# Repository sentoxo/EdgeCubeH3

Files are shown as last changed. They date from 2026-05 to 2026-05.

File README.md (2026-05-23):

# EdgeCubeH3
Work in proggress

Custom, cheap, simple and hand-solder single-board computer with allwinner H3 CPU. Compatibilie with Orange Pi One OS's likes Armbian.

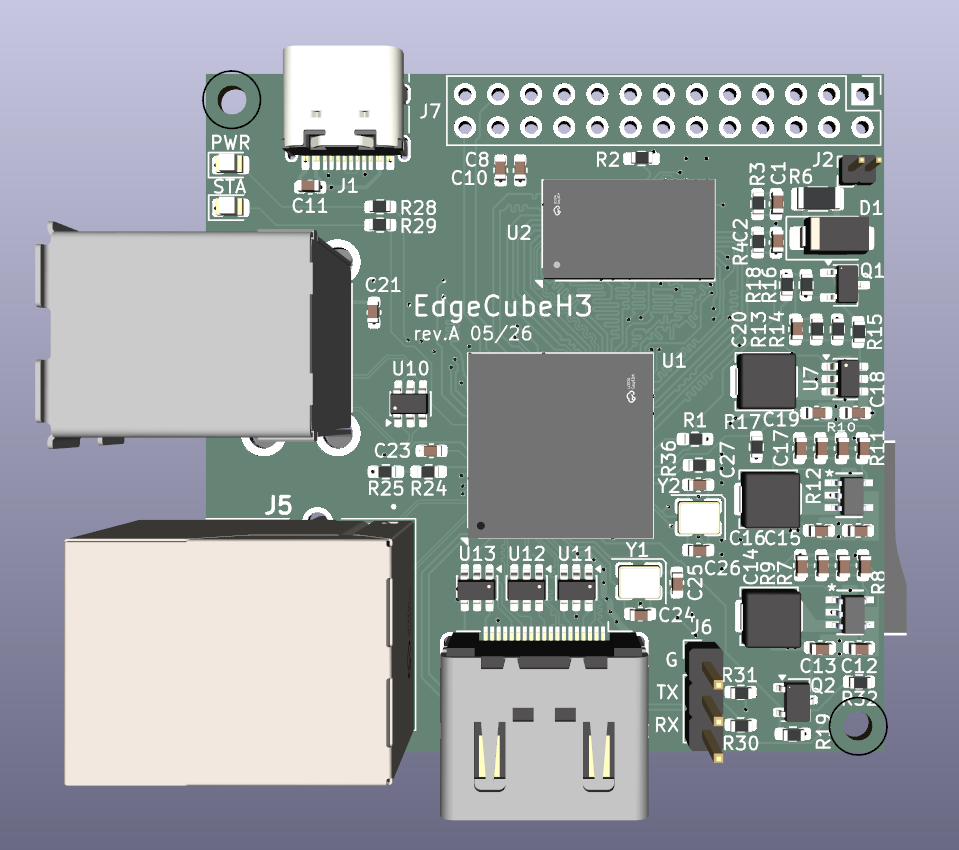
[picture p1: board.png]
board2 image


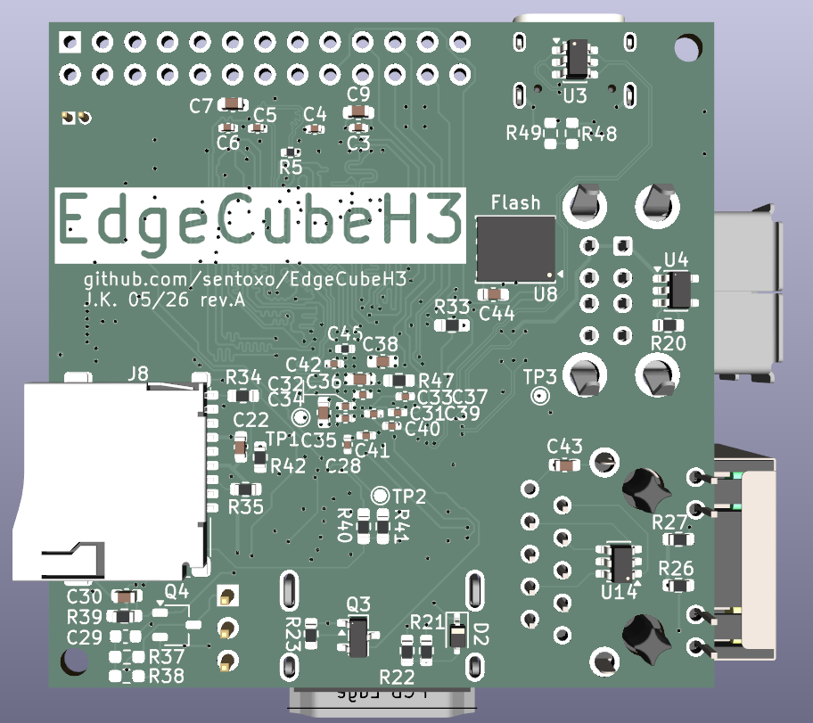
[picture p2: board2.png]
board image


## Features

- H3 Quad-Core ARM Cortex-A7 @ 1.2GHz CPU
    - Mali400 MP2 OpenGL ES 2.0 GPU
- 512MiB of DDR3L RAM, 16b
- 16MB SPI FLASH (Optional)
- Ethernet PHY, 100Mb/s
- GPDI video out
- USB connectors:
    - 2x USB-A 
    - 1x USB-C
- uSD card slot
- GPIO
- Small format 52x52mm

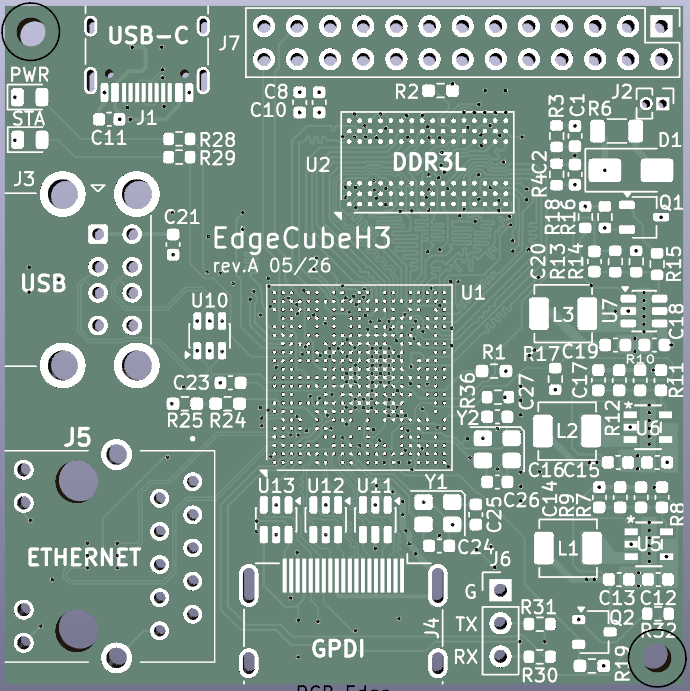
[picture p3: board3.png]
board image


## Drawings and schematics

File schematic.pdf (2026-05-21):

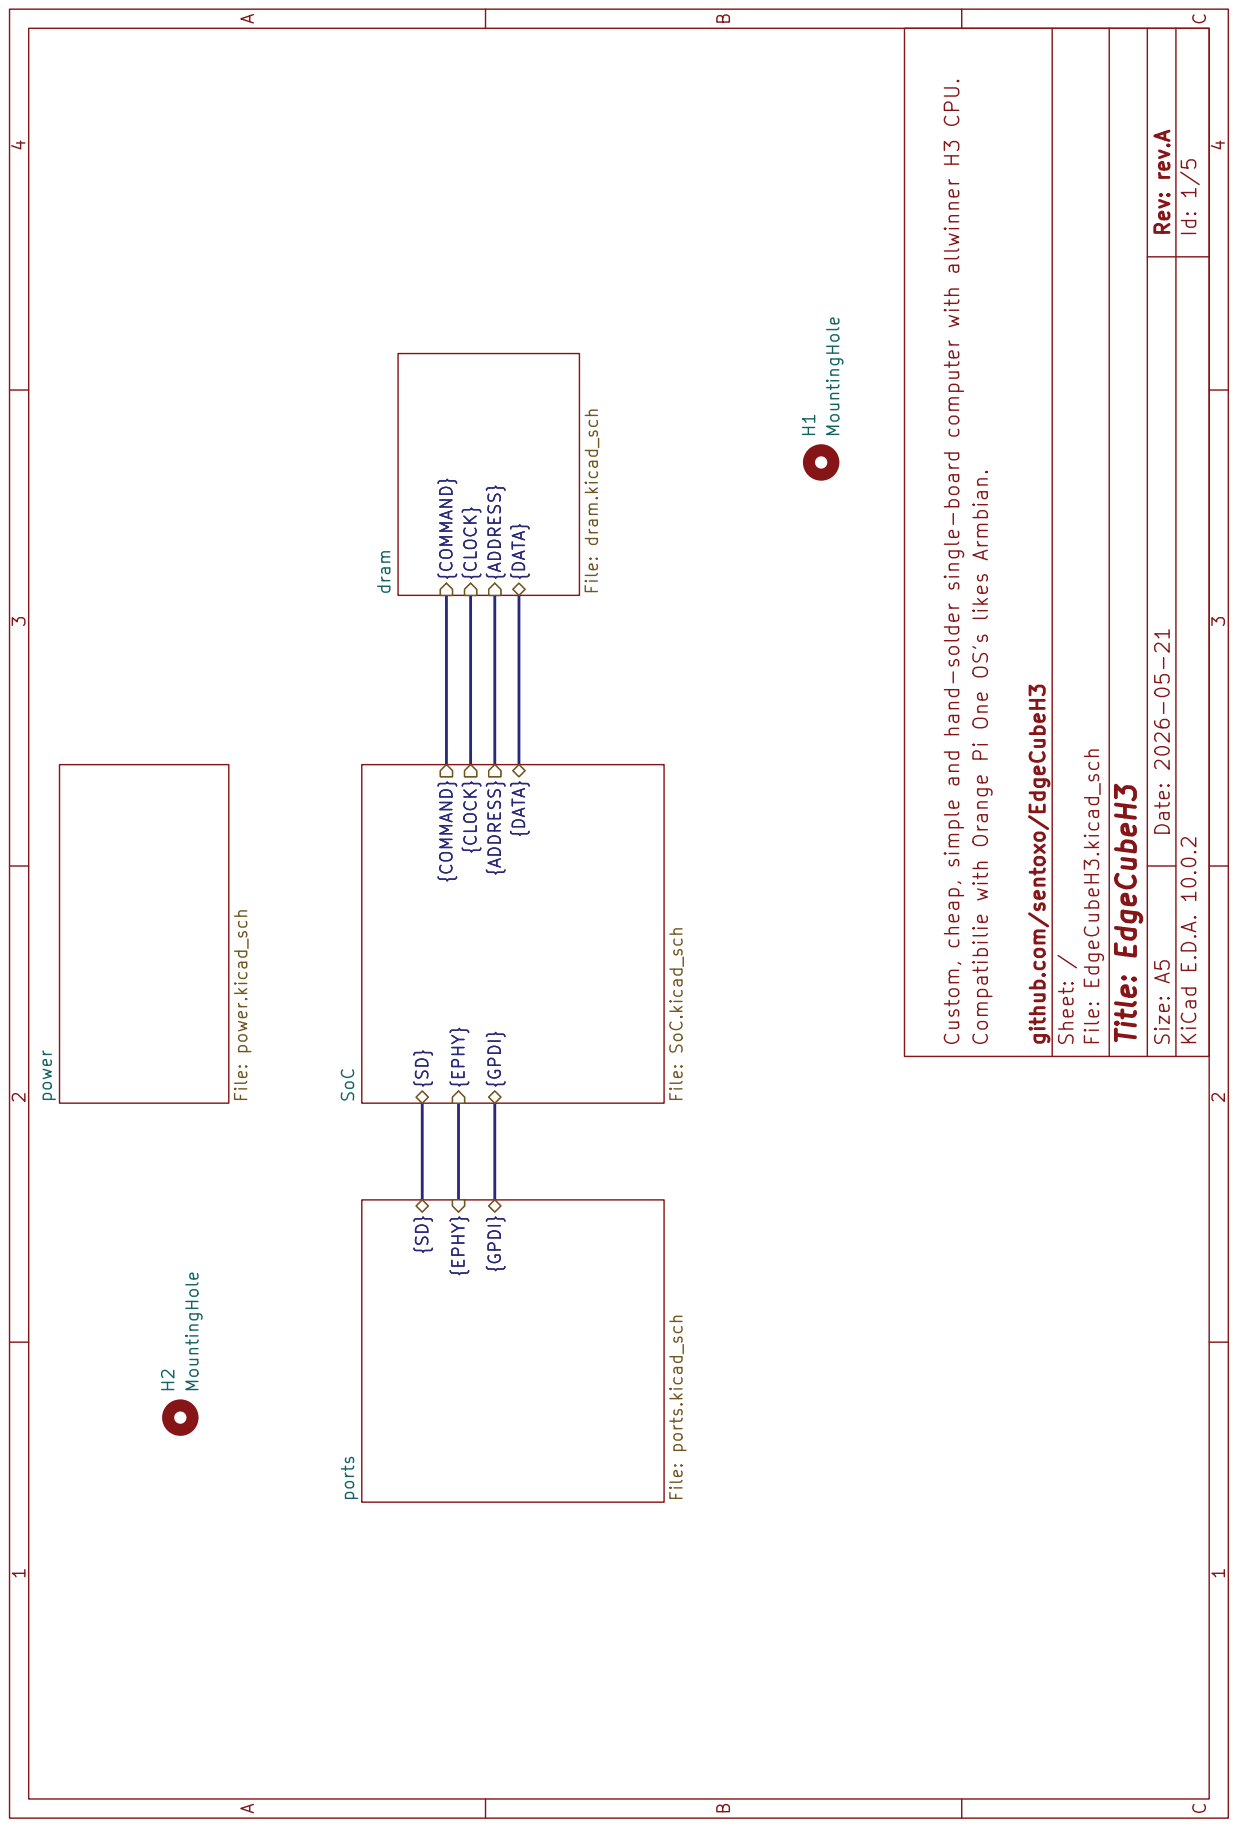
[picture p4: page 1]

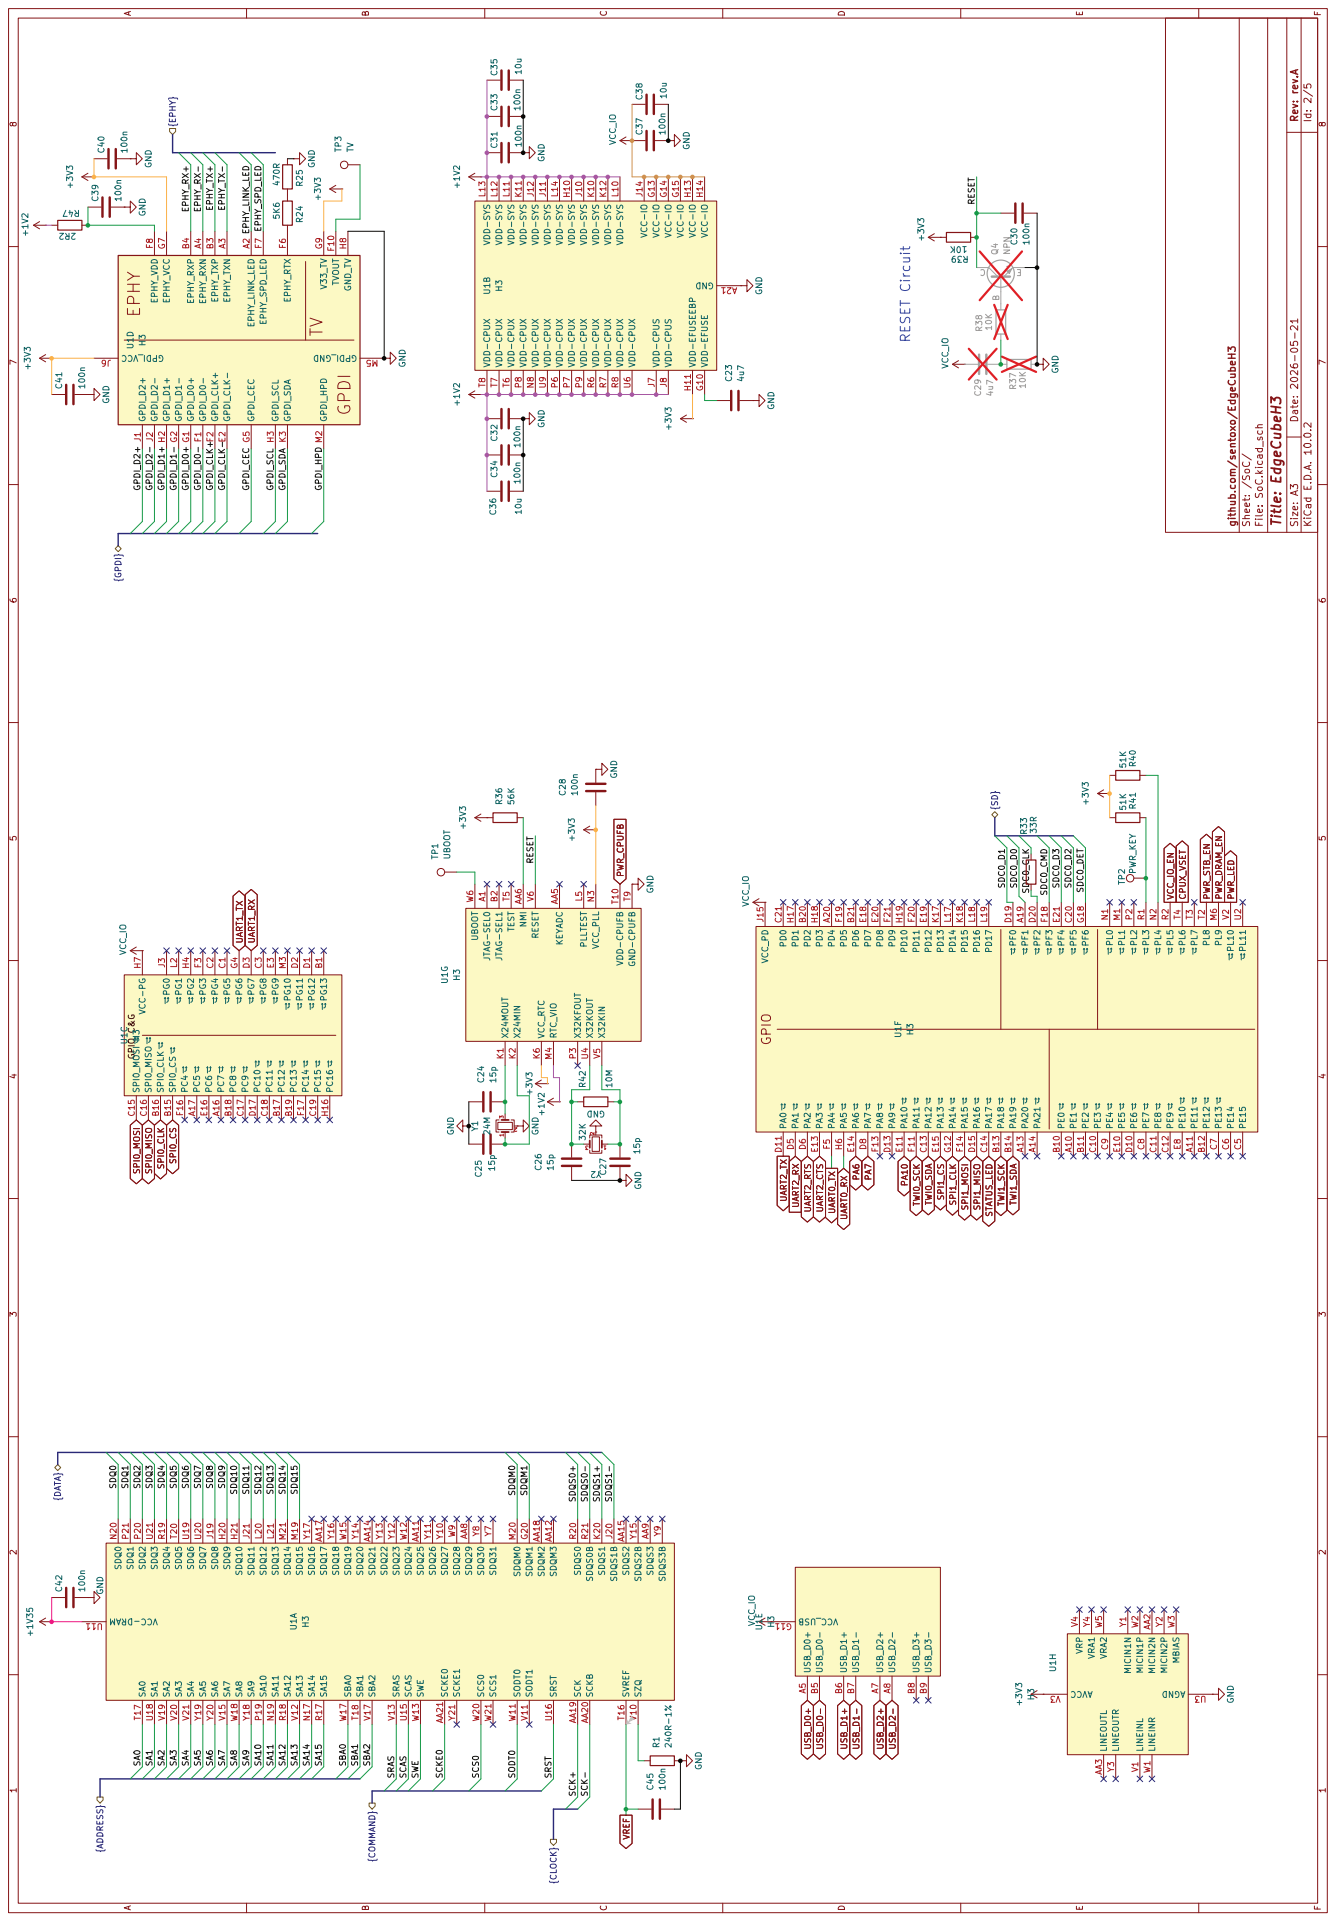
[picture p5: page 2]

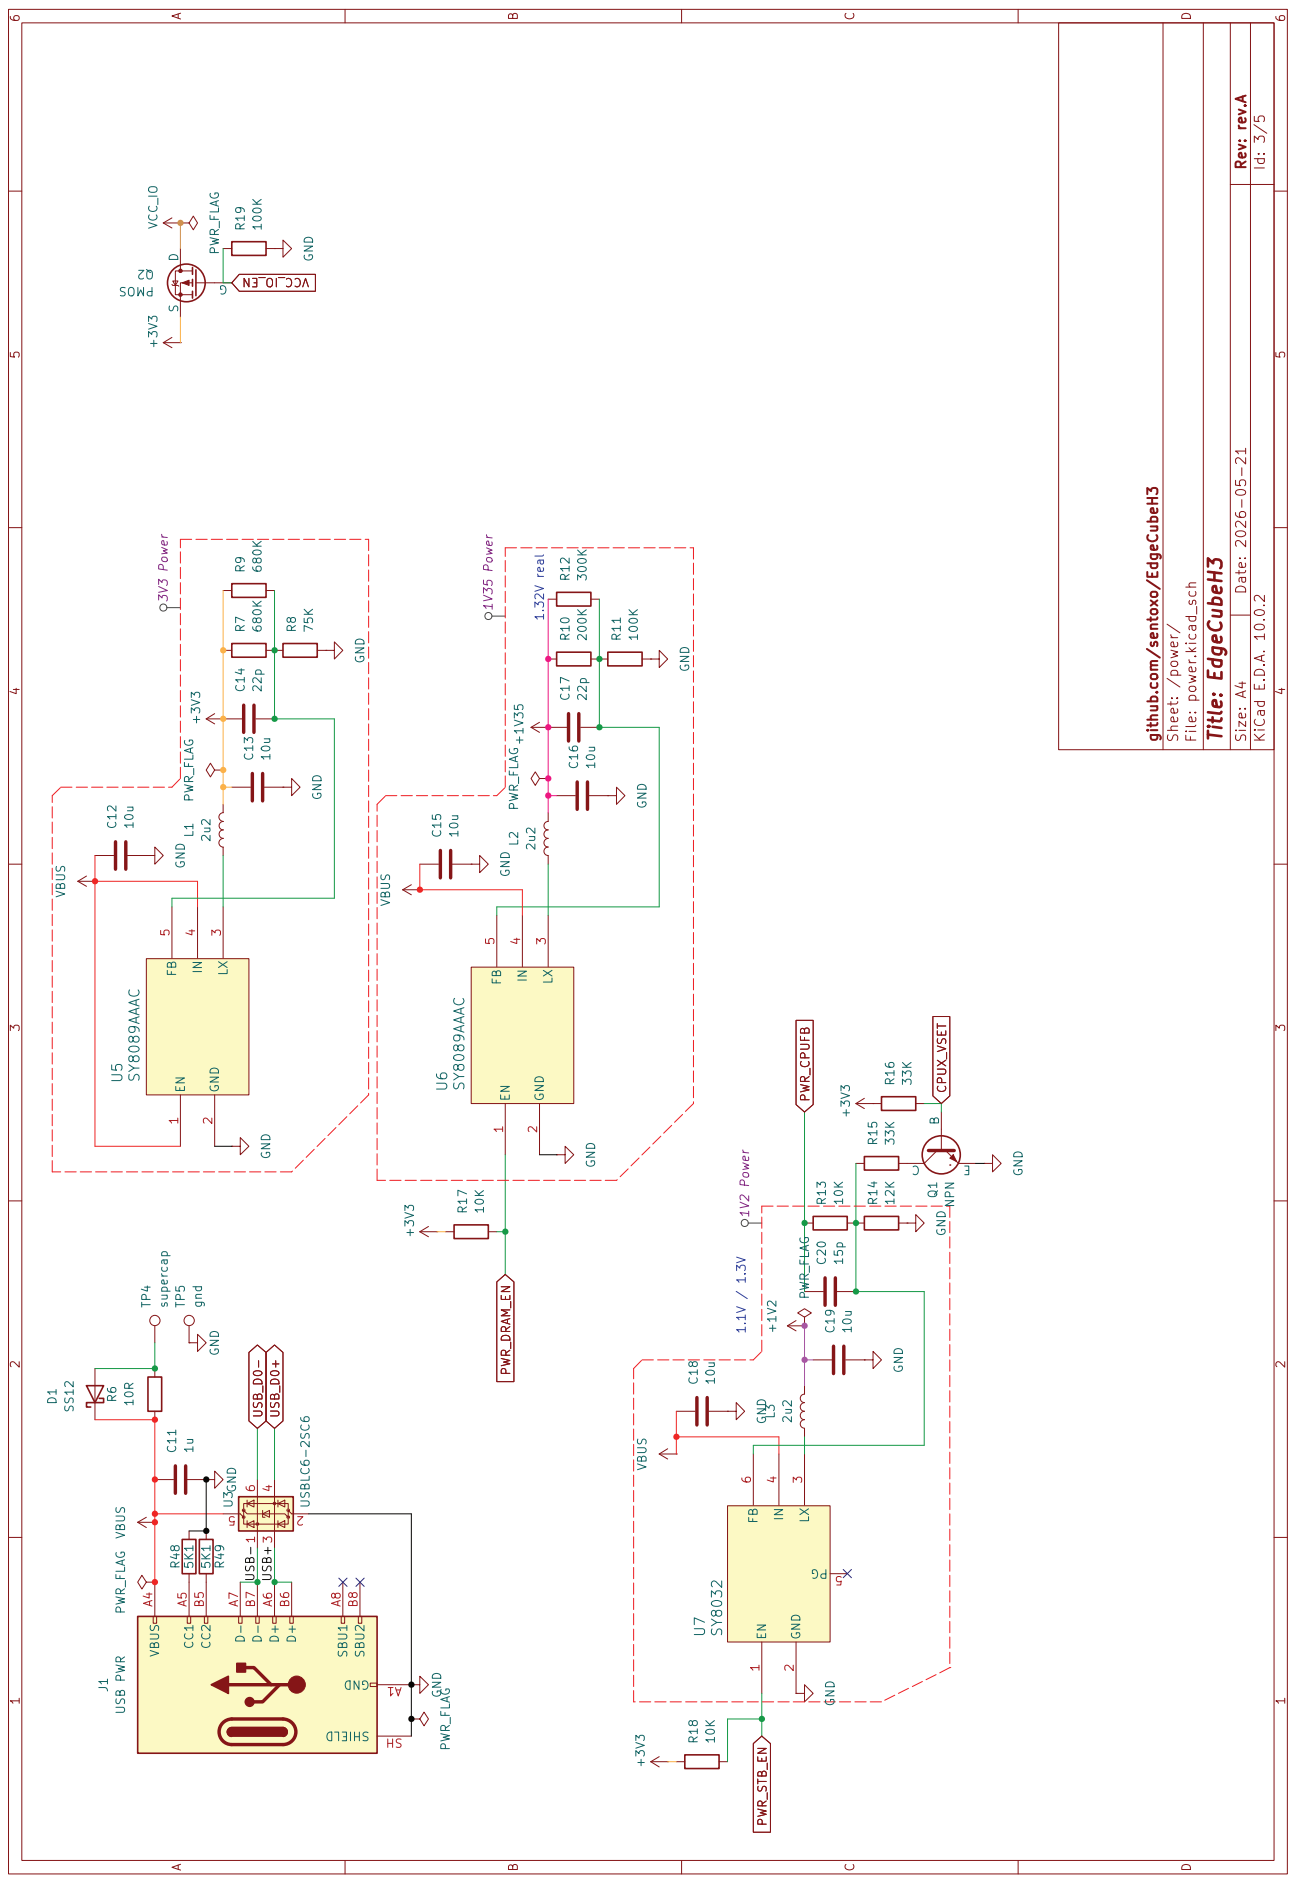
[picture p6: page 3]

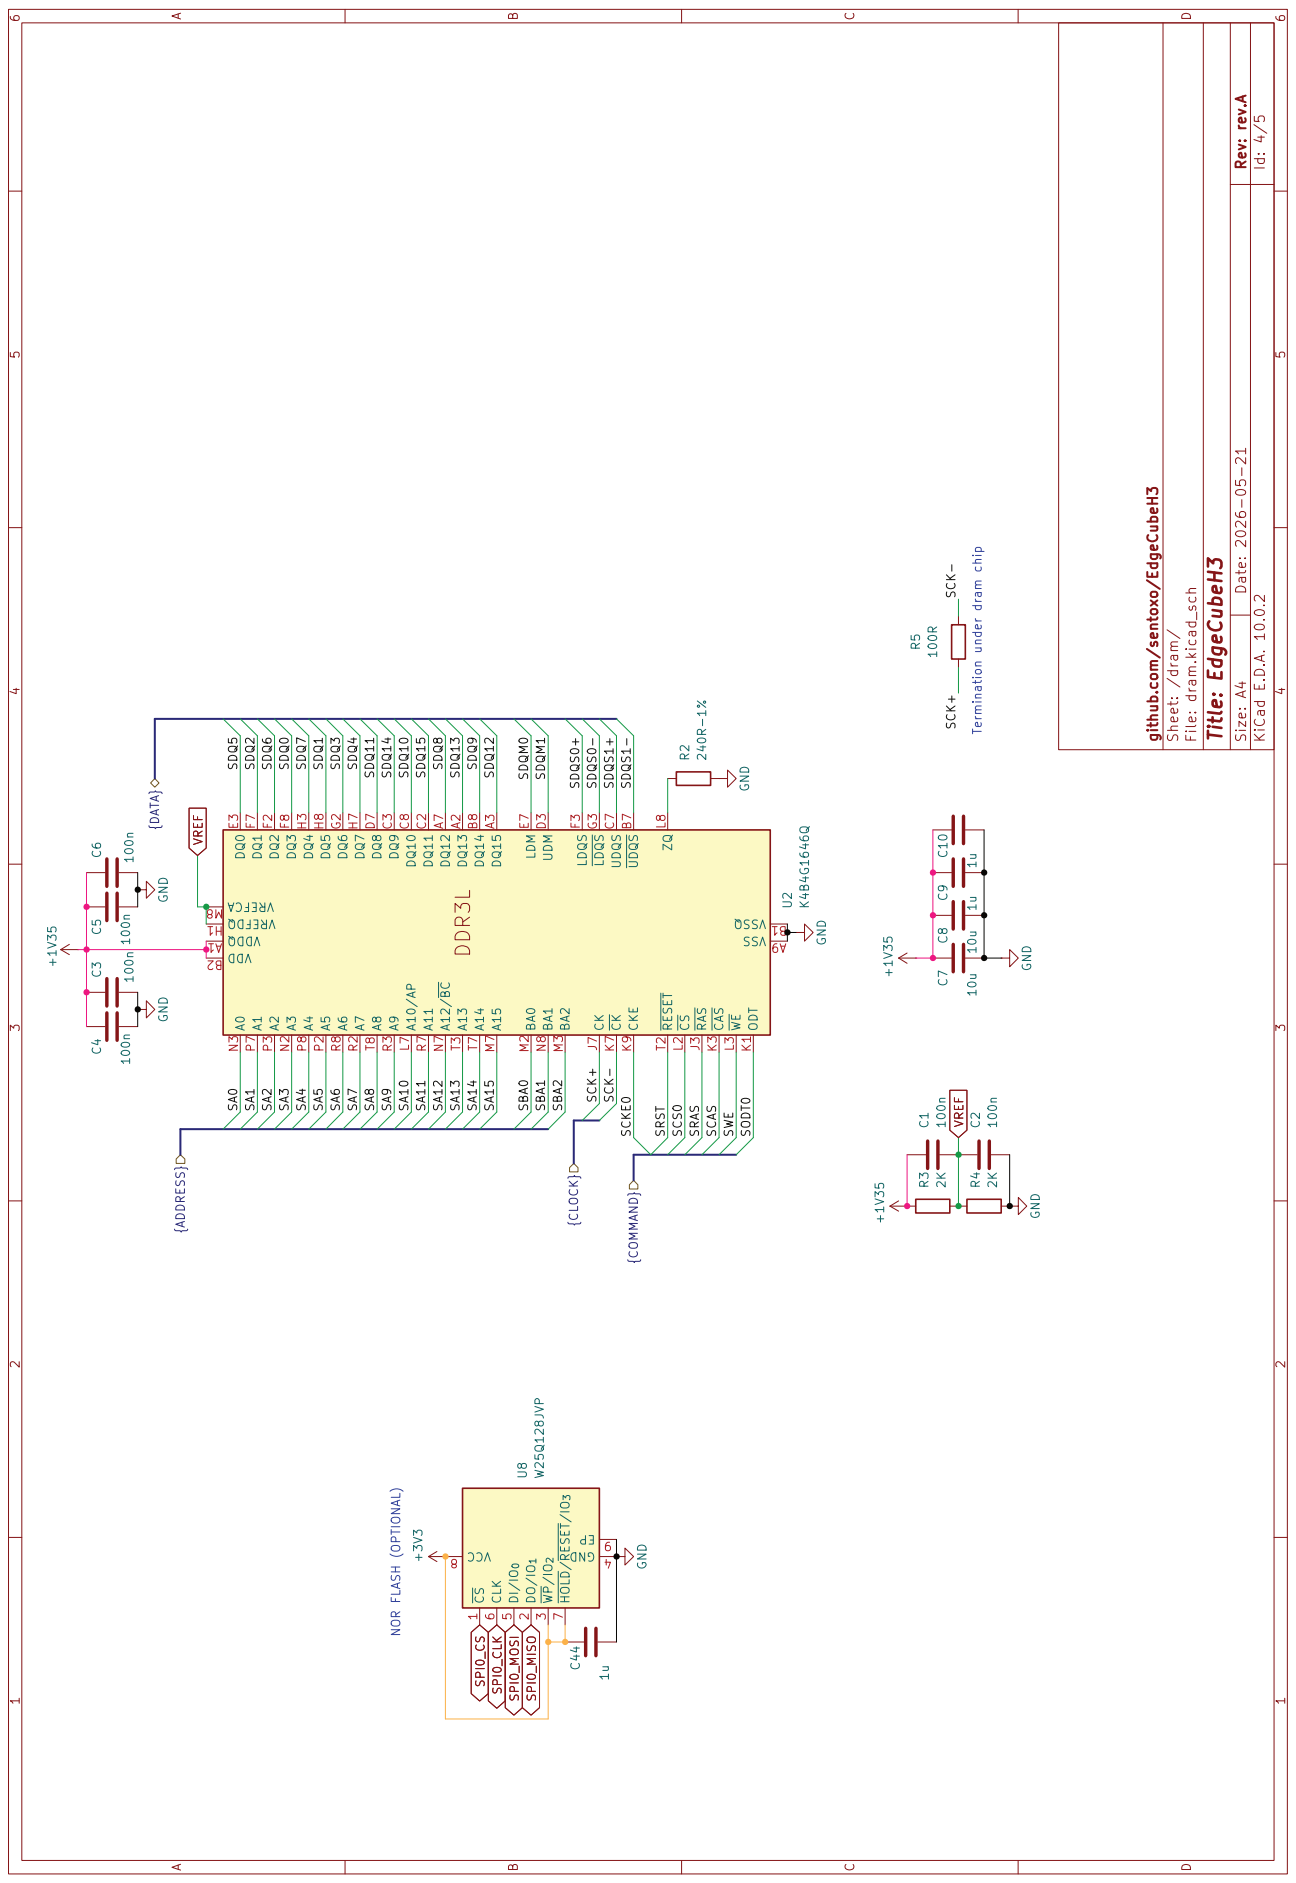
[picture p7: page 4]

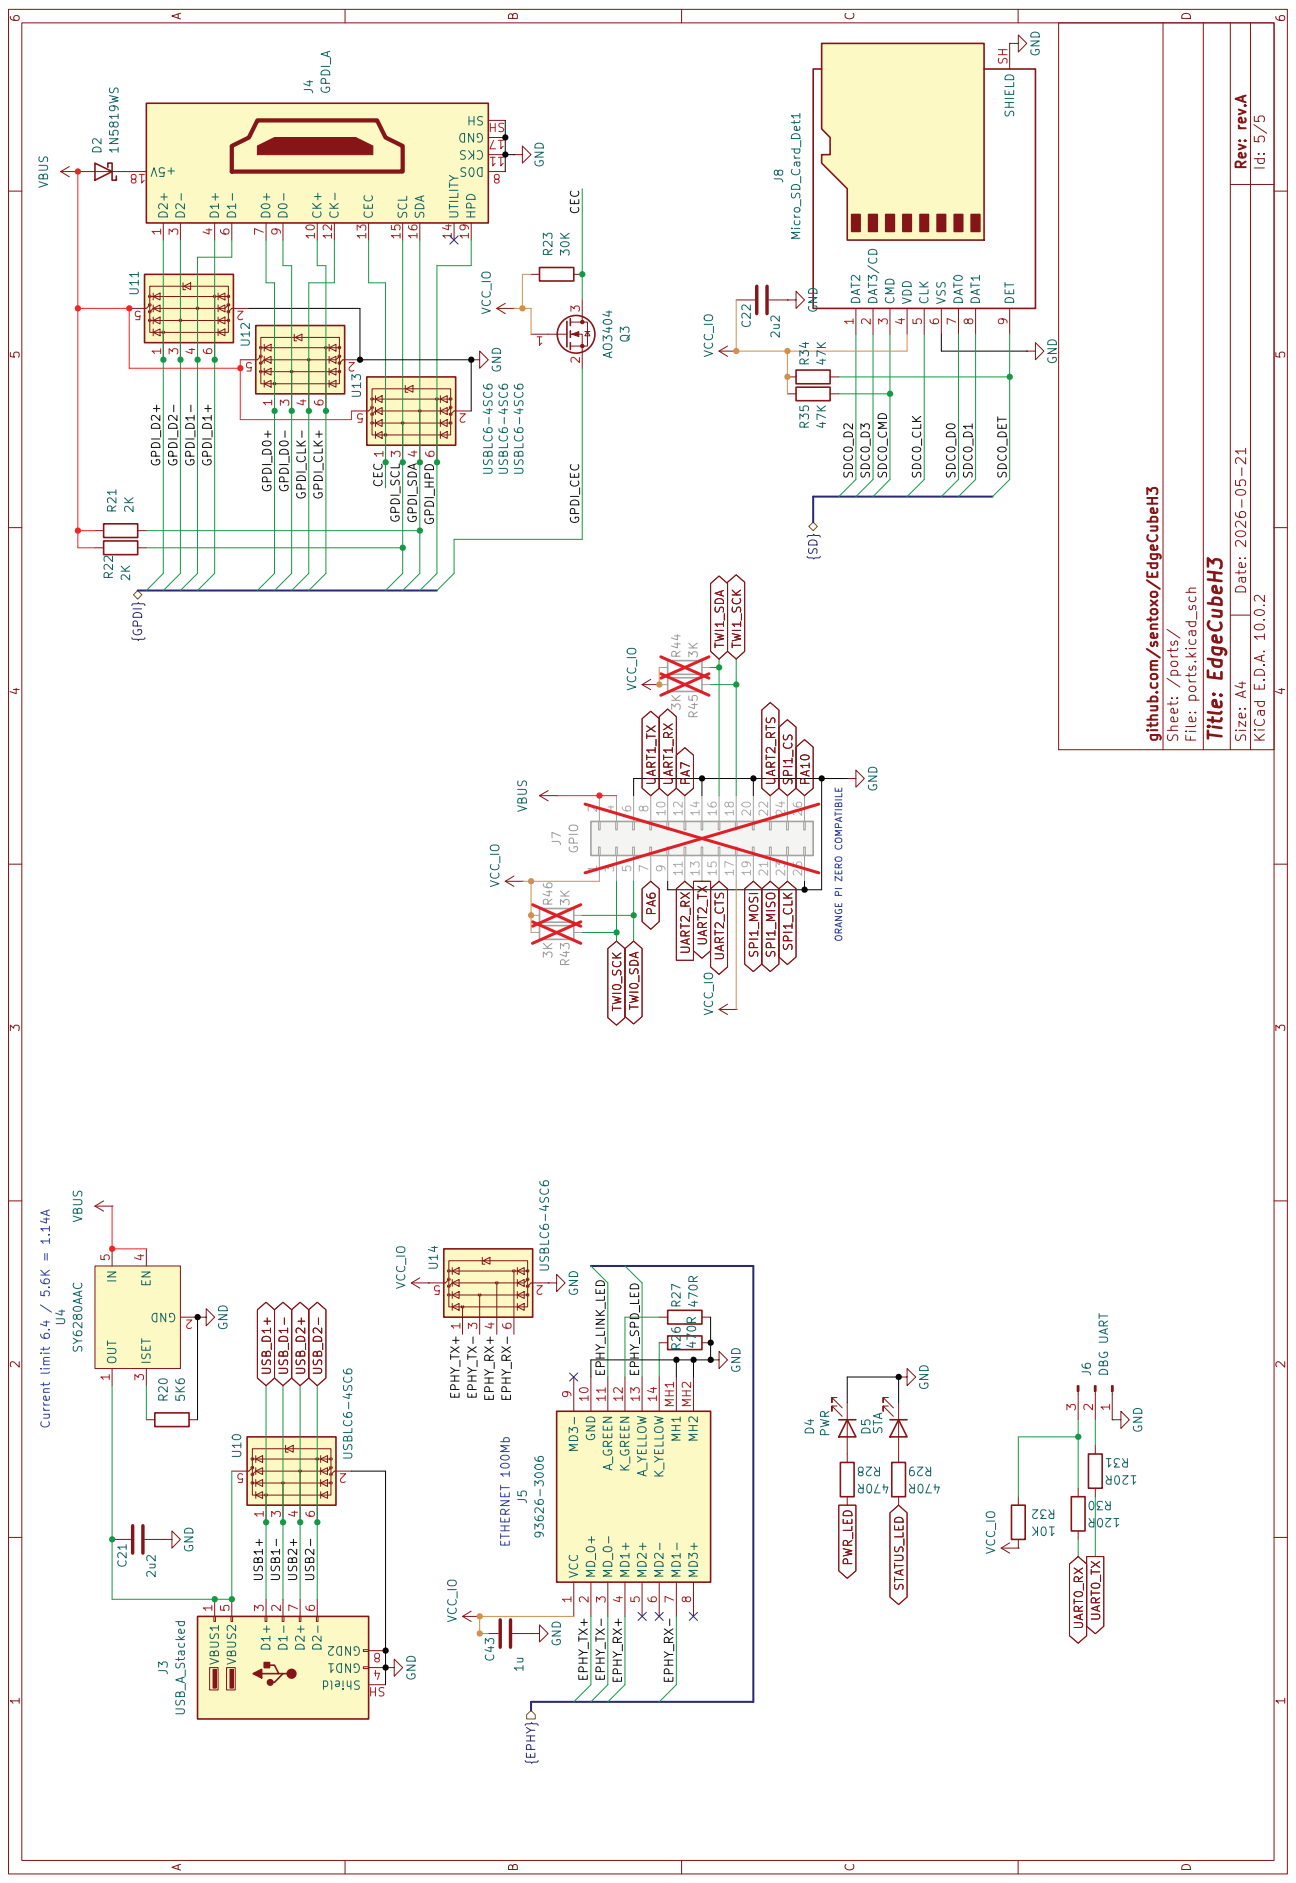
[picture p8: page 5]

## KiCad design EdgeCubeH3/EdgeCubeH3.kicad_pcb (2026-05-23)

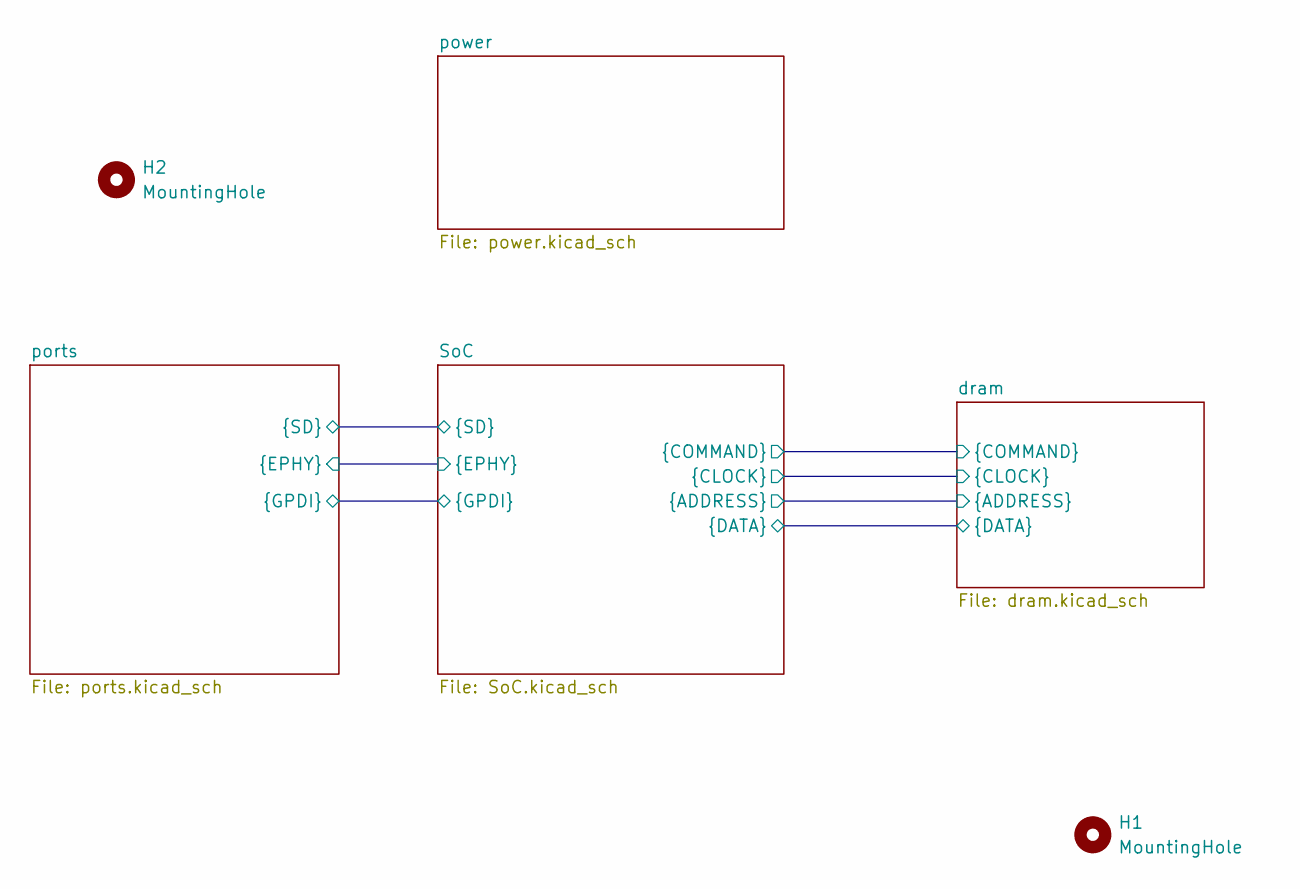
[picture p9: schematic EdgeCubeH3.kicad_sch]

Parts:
H1, H2: MountingHole; MountingHole_2.2mm_M2

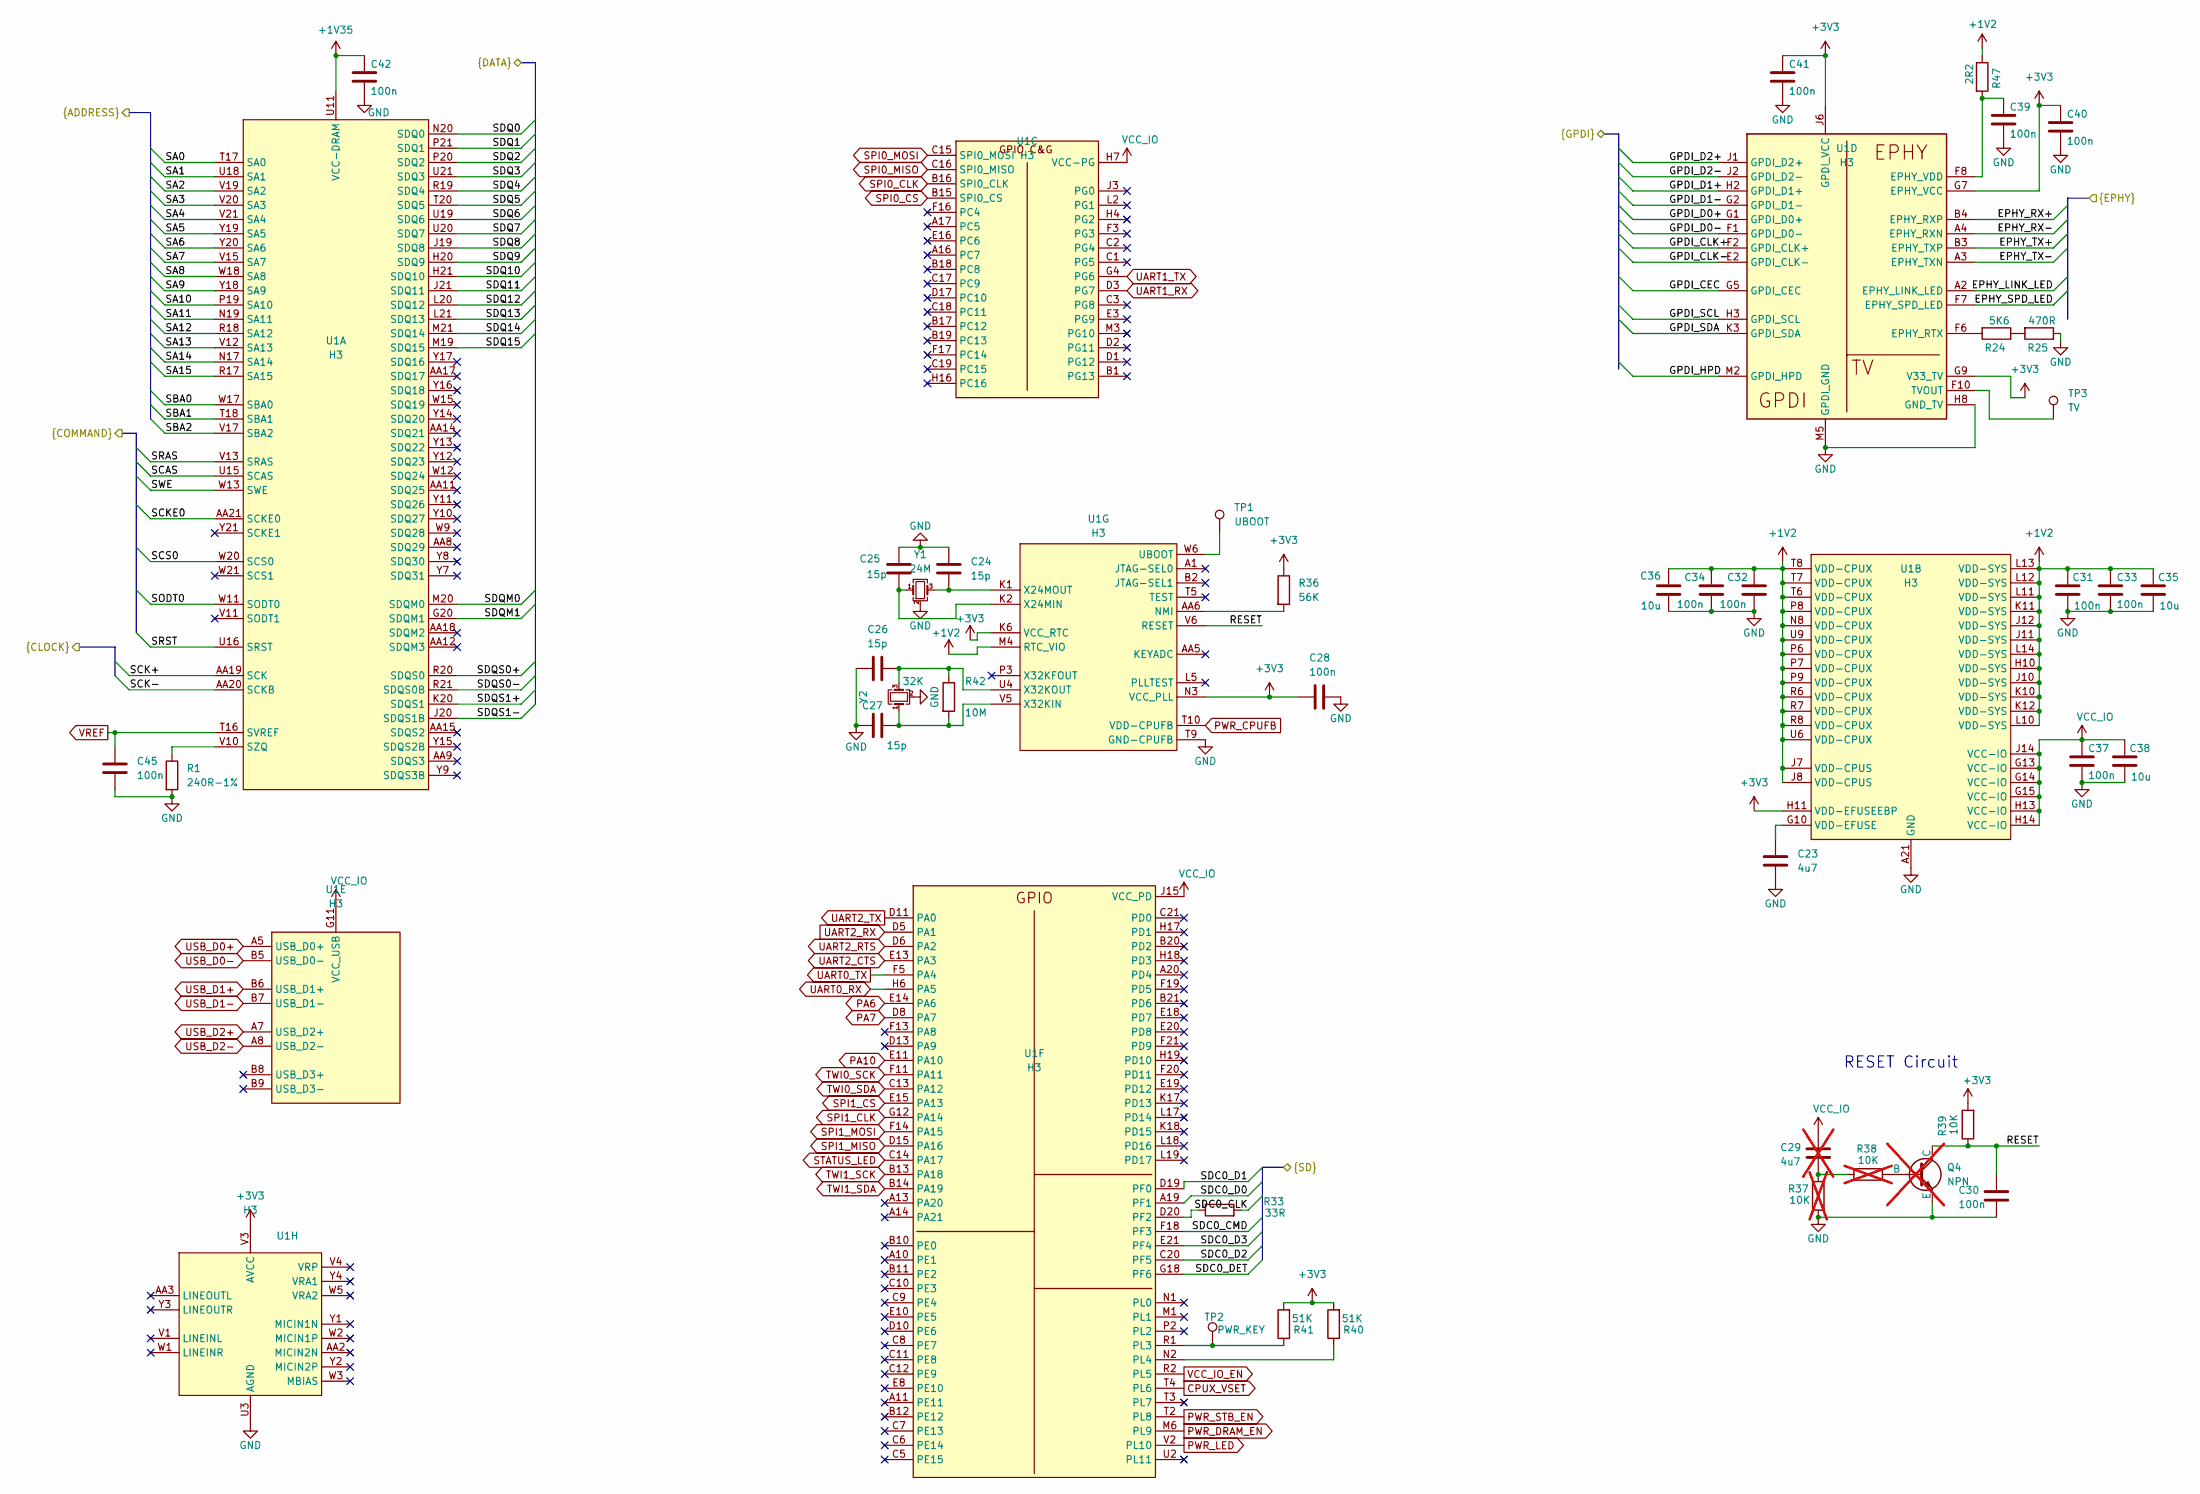
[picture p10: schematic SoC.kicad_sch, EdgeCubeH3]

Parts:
C23: 4u7; C_0603_1608Metric
C24, C25, C26, C27: 15p; C_0603_1608Metric
C28, C31, C32, C33, C34, C37, C39, C40, C41, C42: 100n; C_0402_1005Metric
C29: 4u7; C_0603_1608Metric; not fitted
C30: 100n; C_0603_1608Metric
C35, C36, C38: 10u; C_0603_1608Metric
C45: 100n; R_0402_1005Metric
Q4: NPN; TSOT-23; not fitted
R1: 240R-1%; R_0603_1608Metric_Pad0.98x0.95mm_HandSolder
R24: 5K6; R_0603_1608Metric_Pad0.98x0.95mm_HandSolder
R25: 470R; R_0603_1608Metric_Pad0.98x0.95mm_HandSolder
R33: 33R; R_0603_1608Metric_Pad0.98x0.95mm_HandSolder
R36: 56K; R_0603_1608Metric
R37, R38: 10K; R_0603_1608Metric_Pad0.98x0.95mm_HandSolder; not fitted
R39: 10K; R_0603_1608Metric_Pad0.98x0.95mm_HandSolder
R40, R41: 51K; R_0603_1608Metric_Pad0.98x0.95mm_HandSolder
R42: 10M; R_0603_1608Metric
R47: 2R2; R_0603_1608Metric
TP1: UBOOT; TestPoint_Pad_D1.0mm
TP2: PWR_KEY; TestPoint_Pad_D1.0mm
TP3: TV; TestPoint_Pad_D1.0mm
U1: H3; FBGA-347_14x14mm_Layout21x21_P0.65mm
Y1: 24M; Crystal_SMD_3225-4Pin_3.2x2.5mm
Y2: 32K; Crystal_SMD_3225-4Pin_3.2x2.5mm

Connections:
+1V2: C31.1, C32.1, C33.1, C34.1, C35.1, C36.2, R47.1, U1.H10 (VDD-SYS), U1.J7 (VDD-CPUS), U1.J8 (VDD-CPUS), U1.J10 (VDD-SYS), U1.J11 (VDD-SYS), U1.J12 (VDD-SYS), U1.K10 (VDD-SYS), U1.K11 (VDD-SYS), U1.K12 (VDD-SYS), U1.L10 (VDD-SYS), U1.L11 (VDD-SYS), U1.L12 (VDD-SYS), U1.L13 (VDD-SYS), U1.L14 (VDD-SYS), U1.M4 (RTC_VIO), U1.N8 (VDD-CPUX), U1.P6 (VDD-CPUX), U1.P7 (VDD-CPUX), U1.P8 (VDD-CPUX), U1.P9 (VDD-CPUX), U1.R6 (VDD-CPUX), U1.R7 (VDD-CPUX), U1.R8 (VDD-CPUX), U1.T6 (VDD-CPUX), U1.T7 (VDD-CPUX), U1.T8 (VDD-CPUX), U1.U6 (VDD-CPUX), U1.U9 (VDD-CPUX); also elsewhere on the board
+1V35: C42.1, U1.L16 (VCC-DRAM), U1.M16 (VCC-DRAM), U1.N16 (VCC-DRAM), U1.P16 (VCC-DRAM), U1.P17 (VCC-DRAM), U1.R16 (VCC-DRAM), U1.T12 (VCC-DRAM), U1.T13 (VCC-DRAM), U1.T14 (VCC-DRAM), U1.T15 (VCC-DRAM), U1.U11 (VCC-DRAM); also elsewhere on the board
+3V3: C28.1, C40.1, C41.1, R36.1, R39.2, R40.2, R41.2, U1.G7 (EPHY_VCC), U1.G9 (V33_TV), U1.H11 (VDD-EFUSEEBP), U1.J6 (GPDI_VCC), U1.K6 (VCC_RTC), U1.N3 (VCC_PLL), U1.V3 (AVCC); also elsewhere on the board
/SoC/EPHY_LINK_LED: U1.A2 (EPHY_LINK_LED); also elsewhere on the board
/SoC/EPHY_RX+: U1.B4 (EPHY_RXP); also elsewhere on the board
/SoC/EPHY_RX-: U1.A4 (EPHY_RXN); also elsewhere on the board
/SoC/EPHY_SPD_LED: U1.F7 (EPHY_SPD_LED); also elsewhere on the board
/SoC/EPHY_TX+: U1.B3 (EPHY_TXP); also elsewhere on the board
/SoC/EPHY_TX-: U1.A3 (EPHY_TXN); also elsewhere on the board
/SoC/GPDI_CEC: U1.G5 (GPDI_CEC); also elsewhere on the board
/SoC/GPDI_CLK+: U1.F2 (GPDI_CLK+); also elsewhere on the board
/SoC/GPDI_CLK-: U1.E2 (GPDI_CLK-); also elsewhere on the board
/SoC/GPDI_D0+: U1.G1 (GPDI_D0+); also elsewhere on the board
/SoC/GPDI_D0-: U1.F1 (GPDI_D0-); also elsewhere on the board
/SoC/GPDI_D1+: U1.H2 (GPDI_D1+); also elsewhere on the board
/SoC/GPDI_D1-: U1.G2 (GPDI_D1-); also elsewhere on the board
/SoC/GPDI_D2+: U1.J1 (GPDI_D2+); also elsewhere on the board
/SoC/GPDI_D2-: U1.J2 (GPDI_D2-); also elsewhere on the board
/SoC/GPDI_HPD: U1.M2 (GPDI_HPD); also elsewhere on the board
/SoC/GPDI_SCL: U1.H3 (GPDI_SCL); also elsewhere on the board
/SoC/GPDI_SDA: U1.K3 (GPDI_SDA); also elsewhere on the board
/SoC/RESET: C30.1, Q4.1 (C), R39.1, U1.V6 (RESET)
/SoC/SA0: U1.T17 (SA0); also elsewhere on the board
/SoC/SA1: U1.U18 (SA1); also elsewhere on the board
/SoC/SA2: U1.V19 (SA2); also elsewhere on the board
/SoC/SA3: U1.V20 (SA3); also elsewhere on the board
/SoC/SA4: U1.V21 (SA4); also elsewhere on the board
/SoC/SA5: U1.Y19 (SA5); also elsewhere on the board
/SoC/SA6: U1.Y20 (SA6); also elsewhere on the board
/SoC/SA7: U1.V15 (SA7); also elsewhere on the board
/SoC/SA8: U1.W18 (SA8); also elsewhere on the board
/SoC/SA9: U1.Y18 (SA9); also elsewhere on the board
/SoC/SA10: U1.P19 (SA10); also elsewhere on the board
/SoC/SA11: U1.N19 (SA11); also elsewhere on the board
/SoC/SA12: U1.R18 (SA12); also elsewhere on the board
/SoC/SA13: U1.V12 (SA13); also elsewhere on the board
/SoC/SA14: U1.N17 (SA14); also elsewhere on the board
/SoC/SA15: U1.R17 (SA15); also elsewhere on the board
/SoC/SBA0: U1.W17 (SBA0); also elsewhere on the board
/SoC/SBA1: U1.T18 (SBA1); also elsewhere on the board
/SoC/SBA2: U1.V17 (SBA2); also elsewhere on the board
/SoC/SCAS: U1.U15 (SCAS); also elsewhere on the board
/SoC/SCK+: U1.AA19 (SCK); also elsewhere on the board
/SoC/SCK-: U1.AA20 (SCKB); also elsewhere on the board
/SoC/SCKE0: U1.AA21 (SCKE0); also elsewhere on the board
/SoC/SCS0: U1.W20 (SCS0); also elsewhere on the board
/SoC/SDC0_CLK: R33.2; also elsewhere on the board
/SoC/SDC0_CMD: U1.F18 (PF3); also elsewhere on the board
/SoC/SDC0_D0: U1.A19 (PF1); also elsewhere on the board
/SoC/SDC0_D1: U1.D19 (PF0); also elsewhere on the board
/SoC/SDC0_D2: U1.C20 (PF5); also elsewhere on the board
/SoC/SDC0_D3: U1.E21 (PF4); also elsewhere on the board
/SoC/SDC0_DET: U1.G18 (PF6); also elsewhere on the board
/SoC/SDQ0: U1.N20 (SDQ0); also elsewhere on the board
/SoC/SDQ1: U1.P21 (SDQ1); also elsewhere on the board
/SoC/SDQ2: U1.P20 (SDQ2); also elsewhere on the board
/SoC/SDQ3: U1.U21 (SDQ3); also elsewhere on the board
/SoC/SDQ4: U1.R19 (SDQ4); also elsewhere on the board
/SoC/SDQ5: U1.T20 (SDQ5); also elsewhere on the board
/SoC/SDQ6: U1.U19 (SDQ6); also elsewhere on the board
/SoC/SDQ7: U1.U20 (SDQ7); also elsewhere on the board
/SoC/SDQ8: U1.J19 (SDQ8); also elsewhere on the board
/SoC/SDQ9: U1.H20 (SDQ9); also elsewhere on the board
/SoC/SDQ10: U1.H21 (SDQ10); also elsewhere on the board
/SoC/SDQ11: U1.J21 (SDQ11); also elsewhere on the board
/SoC/SDQ12: U1.L20 (SDQ12); also elsewhere on the board
/SoC/SDQ13: U1.L21 (SDQ13); also elsewhere on the board
/SoC/SDQ14: U1.M21 (SDQ14); also elsewhere on the board
/SoC/SDQ15: U1.M19 (SDQ15); also elsewhere on the board
/SoC/SDQM0: U1.M20 (SDQM0); also elsewhere on the board
/SoC/SDQM1: U1.G20 (SDQM1); also elsewhere on the board
/SoC/SDQS0+: U1.R20 (SDQS0); also elsewhere on the board
/SoC/SDQS0-: U1.R21 (SDQS0B); also elsewhere on the board
/SoC/SDQS1+: U1.K20 (SDQS1); also elsewhere on the board
/SoC/SDQS1-: U1.J20 (SDQS1B); also elsewhere on the board
/SoC/SODT0: U1.W11 (SODT0); also elsewhere on the board
/SoC/SRAS: U1.V13 (SRAS); also elsewhere on the board
/SoC/SRST: U1.U16 (SRST); also elsewhere on the board
/SoC/SWE: U1.W13 (SWE); also elsewhere on the board
CPUX_VSET: U1.T4 (PL6); also elsewhere on the board
GND: C23.2, C24.1, C25.2, C26.1, C27.1, C28.2, C30.2, C31.2, C32.2, C33.2, C34.2, C35.2, C36.1, C37.2, C38.2, C39.2, C40.2, C41.2, C42.2, C45.2, Q4.3 (E), R1.2, R25.1, R37.2, U1.A21 (GND), U1.AA1 (GND), U1.G8 (GND), U1.H8 (GND_TV), U1.H12 (GND), U1.H15 (GND), U1.J9 (GND), U1.J13 (GND), U1.J16 (GND), U1.K7 (GND), U1.K8 (GND), U1.K9 (GND), U1.K13 (GND), U1.K14 (GND), U1.K15 (GND), U1.K16 (GND), U1.L8 (GND), U1.L9 (GND), U1.L15 (GND), U1.M5 (GPDI_GND), U1.M7 (GND), U1.M8 (GND), U1.M9 (GND), U1.M10 (GND), U1.M11 (GND), U1.M12 (GND), U1.M13 (GND), U1.M14 (GND), U1.M15 (GND), U1.N7 (GND), U1.N9 (GND), U1.N10 (GND), U1.N11 (GND), U1.N12 (GND), U1.N13 (GND), U1.N14 (GND), U1.N15 (GND), U1.P10 (GND), U1.P11 (GND), U1.P12 (GND), U1.P13 (GND), U1.P14 (GND), U1.P15 (GND), U1.R9 (GND), U1.R10 (GND), U1.R11 (GND), U1.R12 (GND), U1.R13 (GND), U1.R14 (GND), U1.T9 (GND-CPUFB), U1.T11 (GND), U1.U3 (AGND), Y1.2 (G), Y1.4 (G), Y2.2 (G), Y2.4 (G); also elsewhere on the board
unnamed: C29.2, R37.1, R38.1
unnamed: Q4.2 (B), R38.2
unnamed: R24.1, R25.2
unnamed: R1.1, U1.V10 (SZQ)
unnamed: C23.1, U1.G10 (VDD-EFUSE)
unnamed: R24.2, U1.F6 (EPHY_RTX)
unnamed: C39.1, R47.2, U1.F8 (EPHY_VDD)
unnamed: TP3.1 (1_1), U1.F10 (TVOUT)
unnamed: R33.1, U1.D20 (PF2)
unnamed: R41.1, TP2.1 (1_1), U1.R1 (PL3)
unnamed: R40.1, U1.N2 (PL4)
unnamed: R36.2, U1.AA6 (NMI)
unnamed: TP1.1 (1_1), U1.W6 (UBOOT)
unnamed: C25.1, U1.K2 (X24MIN), Y1.1
unnamed: C24.2, U1.K1 (X24MOUT), Y1.3
unnamed: C27.2, R42.2, U1.V5 (X32KIN), Y2.1
unnamed: C26.2, R42.1, U1.U4 (X32KOUT), Y2.3
PA6: U1.E14 (PA6); also elsewhere on the board
PA7: U1.D8 (PA7); also elsewhere on the board
PA10: U1.E11 (PA10); also elsewhere on the board
PWR_CPUFB: U1.T10 (VDD-CPUFB); also elsewhere on the board
PWR_DRAM_EN: U1.M6 (PL9); also elsewhere on the board
PWR_LED: U1.V2 (PL10); also elsewhere on the board
PWR_STB_EN: U1.T2 (PL8); also elsewhere on the board
SPI0_CLK: U1.B16 (SPI0_CLK); also elsewhere on the board
SPI0_CS: U1.B15 (SPI0_CS); also elsewhere on the board
SPI0_MISO: U1.C16 (SPI0_MISO); also elsewhere on the board
SPI0_MOSI: U1.C15 (SPI0_MOSI); also elsewhere on the board
SPI1_CLK: U1.G12 (PA14); also elsewhere on the board
SPI1_CS: U1.E15 (PA13); also elsewhere on the board
SPI1_MISO: U1.D15 (PA16); also elsewhere on the board
SPI1_MOSI: U1.F14 (PA15); also elsewhere on the board
STATUS_LED: U1.C14 (PA17); also elsewhere on the board
TWI0_SCK: U1.F11 (PA11); also elsewhere on the board
TWI0_SDA: U1.C13 (PA12); also elsewhere on the board
TWI1_SCK: U1.B13 (PA18); also elsewhere on the board
TWI1_SDA: U1.B14 (PA19); also elsewhere on the board
UART0_RX: U1.H6 (PA5); also elsewhere on the board
UART0_TX: U1.F5 (PA4); also elsewhere on the board
UART1_RX: U1.D3 (PG7); also elsewhere on the board
UART1_TX: U1.G4 (PG6); also elsewhere on the board
UART2_CTS: U1.E13 (PA3); also elsewhere on the board
UART2_RTS: U1.D6 (PA2); also elsewhere on the board
UART2_RX: U1.D5 (PA1); also elsewhere on the board
UART2_TX: U1.D11 (PA0); also elsewhere on the board
USB_D0+: U1.A5 (USB_D0+); also elsewhere on the board
USB_D0-: U1.B5 (USB_D0-); also elsewhere on the board
USB_D1+: U1.B6 (USB_D1+); also elsewhere on the board
USB_D1-: U1.B7 (USB_D1-); also elsewhere on the board
USB_D2+: U1.A7 (USB_D2+); also elsewhere on the board
USB_D2-: U1.A8 (USB_D2-); also elsewhere on the board
VCC_IO: C29.1, C37.1, C38.1, U1.G11 (VCC_USB), U1.G13 (VCC-IO), U1.G14 (VCC-IO), U1.G15 (VCC-IO), U1.H7 (VCC-PG), U1.H13 (VCC-IO), U1.H14 (VCC-IO), U1.J14 (VCC-IO), U1.J15 (VCC_PD); also elsewhere on the board
VCC_IO_EN: U1.R2 (PL5); also elsewhere on the board
VREF: C45.1, U1.T16 (SVREF); also elsewhere on the board

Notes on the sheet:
RESET Circuit

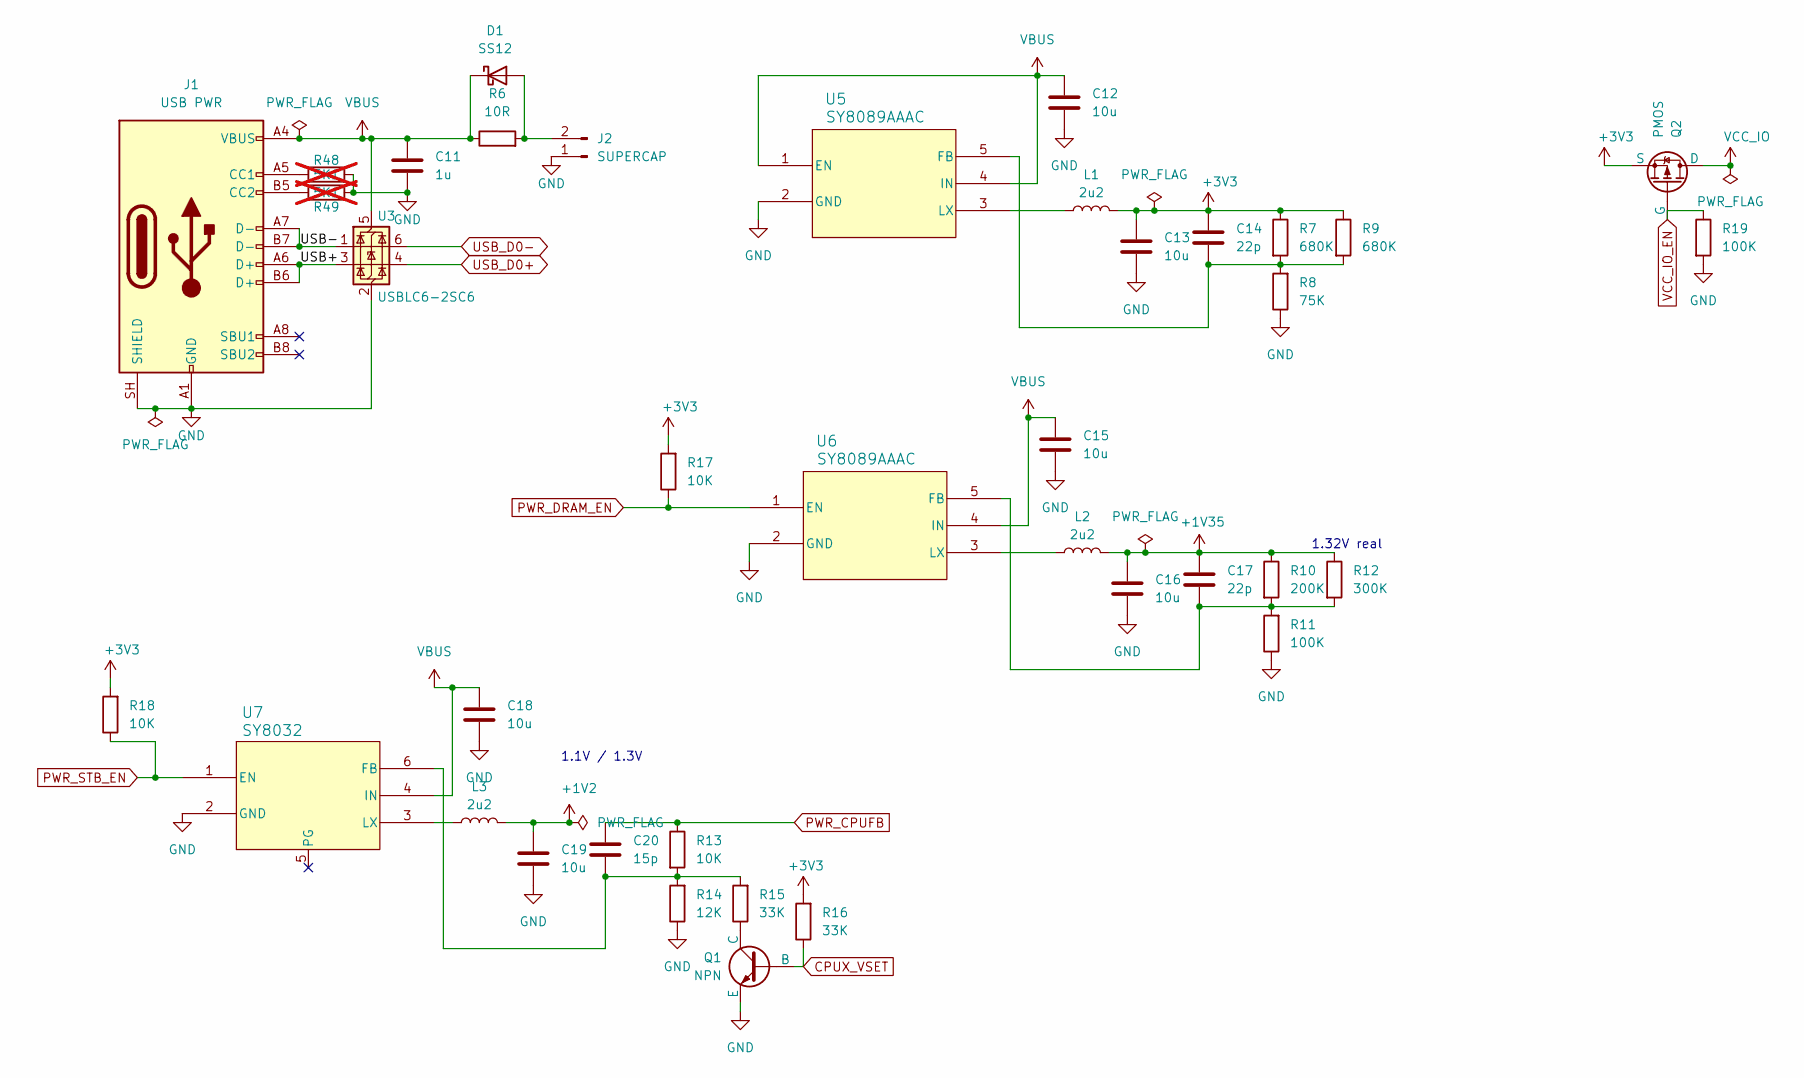
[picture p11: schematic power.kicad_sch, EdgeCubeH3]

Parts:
C11: 1u; C_0603_1608Metric
C12, C13, C15, C16, C18, C19: 10u; C_0603_1608Metric
C14, C17: 22p; C_0603_1608Metric
C20: 15p; C_0603_1608Metric
D1: SS12; D_SMA
J1: USB PWR; USB_C_Receptacle_HRO_TYPE-C-31-M-12
J2: SUPERCAP; PinHeader_1x02_P1.27mm_Vertical
L1, L2, L3: 2u2; L_APV_APH0420
Q1: NPN; TSOT-23
Q2: PMOS; SOT-23W
R6: 10R; R_1206_3216Metric
R7, R9: 680K; C_0603_1608Metric
R8: 75K; C_0603_1608Metric
R10: 200K; C_0603_1608Metric
R11: 100K; C_0603_1608Metric
R12: 300K; C_0603_1608Metric
R13, R17, R18: 10K; R_0603_1608Metric
R14: 12K; R_0603_1608Metric
R15, R16: 33K; R_0603_1608Metric
R19: 100K; R_0603_1608Metric_Pad0.98x0.95mm_HandSolder
R48, R49: 5K1; R_0603_1608Metric; not fitted
U3: USBLC6-2SC6; SOT-23-6
U5, U6: SY8089AAAC; SY8089AAAC_SGY
U7: SY8032; SOT-23-6

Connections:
+1V2: C19.1, L3.2; also elsewhere on the board
+1V35: C16.1, C17.1, L2.2, R10.1, R12.1; also elsewhere on the board
+3V3: C13.1, C14.1, L1.2, Q2.3 (S), R7.1, R9.1, R16.2, R17.2, R18.2; also elsewhere on the board
/power/USB+: J1.A6 (D+), J1.B6 (D+), U3.3 (I/O2)
/power/USB-: J1.A7 (D-), J1.B7 (D-), U3.1 (I/O1)
CPUX_VSET: Q1.2 (B), R16.1; also elsewhere on the board
GND: C11.2, C12.2, C13.2, C15.2, C16.2, C18.2, C19.2, J1.A1 (GND), J1.A12 (GND), J1.B1 (GND), J1.B12 (GND), J1.SH (SHIELD), J2.1, Q1.3 (E), R8.1, R11.1, R14.1, R19.2, R48.2, R49.1, U3.2 (GND), U5.2 (GND), U6.2 (GND), U7.2 (GND); also elsewhere on the board
unnamed: D1.2 (A), J2.2, R6.2
unnamed: J1.A5 (CC1), R48.1
unnamed: J1.B5 (CC2), R49.2
unnamed: Q1.1 (C), R15.1
unnamed: C14.2, R7.2, R8.2, R9.2, U5.5 (FB)
unnamed: L1.1, U5.3 (LX)
unnamed: C17.2, R10.2, R11.2, R12.2, U6.5 (FB)
unnamed: L2.1, U6.3 (LX)
unnamed: C20.2, R13.2, R14.2, R15.2, U7.6 (FB)
unnamed: L3.1, U7.3 (LX)
PWR_CPUFB: C20.1, R13.1; also elsewhere on the board
PWR_DRAM_EN: R17.1, U6.1 (EN); also elsewhere on the board
PWR_STB_EN: R18.1, U7.1 (EN); also elsewhere on the board
USB_D0+: U3.4 (I/O2); also elsewhere on the board
USB_D0-: U3.6 (I/O1); also elsewhere on the board
VBUS: C11.1, C12.1, C15.1, C18.1, D1.1 (K), J1.A4 (VBUS), J1.A9 (VBUS), J1.B4 (VBUS), J1.B9 (VBUS), R6.1, U3.5 (VBUS), U5.1 (EN), U5.4 (IN), U6.4 (IN), U7.4 (IN); also elsewhere on the board
VCC_IO: Q2.1 (D); also elsewhere on the board
VCC_IO_EN: Q2.2 (G), R19.1; also elsewhere on the board

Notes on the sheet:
1.32V real
1.1V / 1.3V

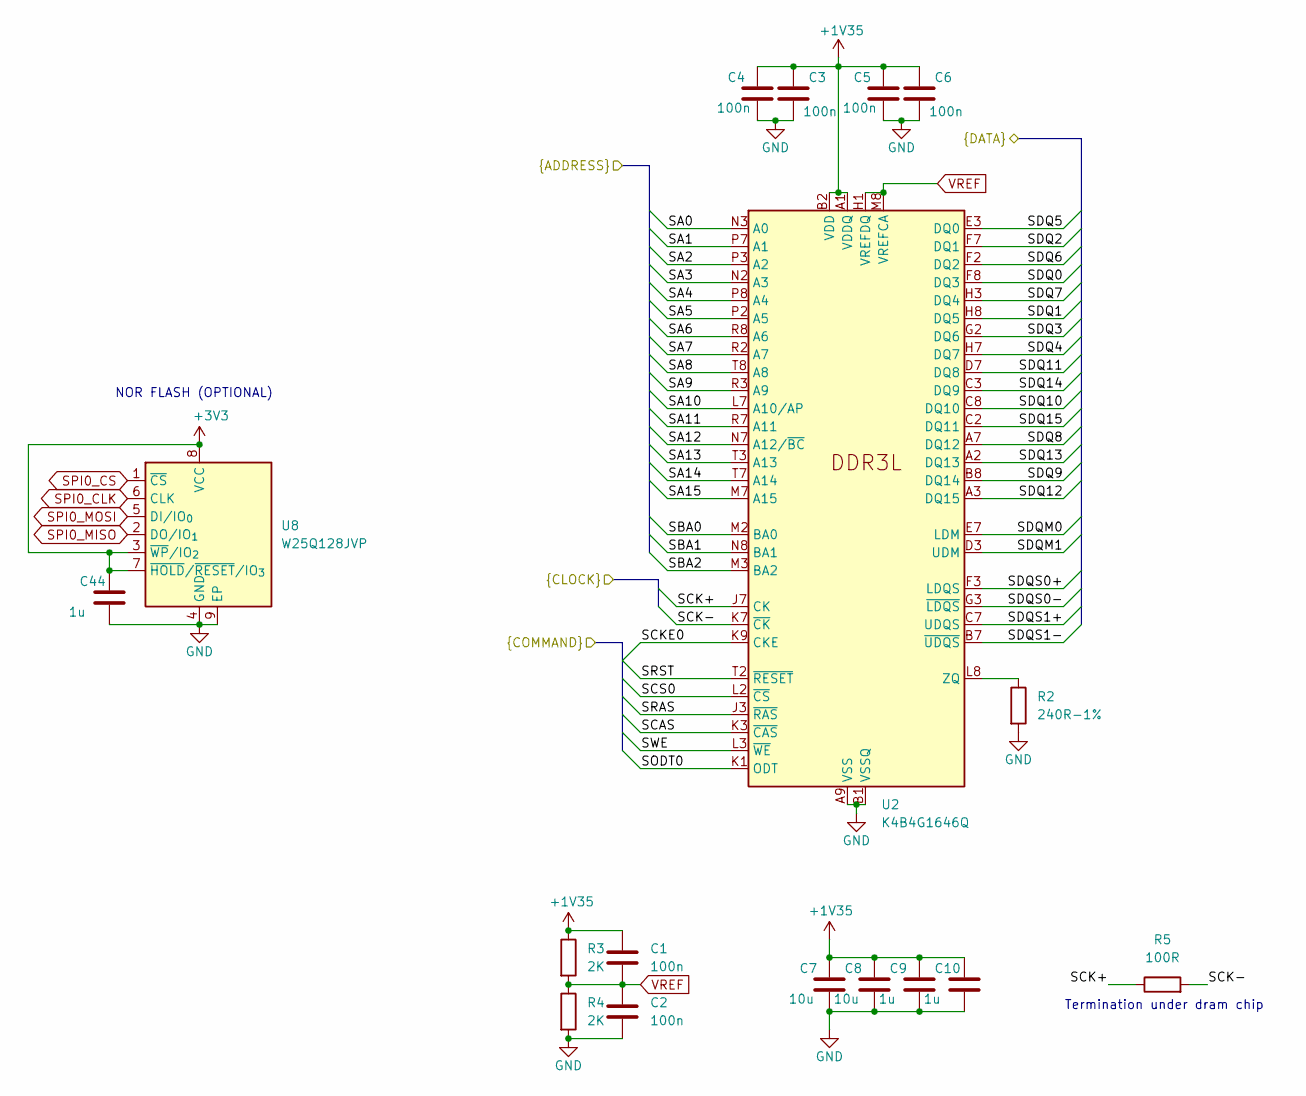
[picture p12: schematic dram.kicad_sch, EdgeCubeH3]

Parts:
C1, C2: 100n; C_0603_1608Metric
C3, C4, C5, C6: 100n; C_0402_1005Metric
C7, C8: 10u; C_0603_1608Metric
C9, C10, C44: 1u; C_0603_1608Metric
R2: 240R-1%; R_0603_1608Metric_Pad0.98x0.95mm_HandSolder
R3, R4: 2K; R_0603_1608Metric
R5: 100R; R_0402_1005Metric
U2: K4B4G1646Q; FBGA-96_7.5x13mm_Layout9x16_P0.8mm
U8: W25Q128JVP; WSON-8-1EP_6x5mm_P1.27mm_EP3.4x4.3mm

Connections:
+1V35: C1.1, C3.1, C4.1, C5.1, C6.1, C7.1, C8.1, C9.1, C10.1, R3.1, U2.A1 (VDDQ), U2.A8 (VDDQ), U2.B2 (VDD), U2.C1 (VDDQ), U2.C9 (VDDQ), U2.D2 (VDDQ), U2.D9 (VDD), U2.E9 (VDDQ), U2.F1 (VDDQ), U2.G7 (VDD), U2.H2 (VDDQ), U2.H9 (VDDQ), U2.K2 (VDD), U2.K8 (VDD), U2.N1 (VDD), U2.N9 (VDD), U2.R1 (VDD), U2.R9 (VDD); also elsewhere on the board
+3V3: C44.1, U8.3 (~WP/IO_{2}), U8.7 (~HOLD/~RESET/IO_{3}), U8.8 (VCC); also elsewhere on the board
/SoC/SA0: U2.N3 (A0); also elsewhere on the board
/SoC/SA1: U2.P7 (A1); also elsewhere on the board
/SoC/SA2: U2.P3 (A2); also elsewhere on the board
/SoC/SA3: U2.N2 (A3); also elsewhere on the board
/SoC/SA4: U2.P8 (A4); also elsewhere on the board
/SoC/SA5: U2.P2 (A5); also elsewhere on the board
/SoC/SA6: U2.R8 (A6); also elsewhere on the board
/SoC/SA7: U2.R2 (A7); also elsewhere on the board
/SoC/SA8: U2.T8 (A8); also elsewhere on the board
/SoC/SA9: U2.R3 (A9); also elsewhere on the board
/SoC/SA10: U2.L7 (A10/AP); also elsewhere on the board
/SoC/SA11: U2.R7 (A11); also elsewhere on the board
/SoC/SA12: U2.N7 (A12/~BC); also elsewhere on the board
/SoC/SA13: U2.T3 (A13); also elsewhere on the board
/SoC/SA14: U2.T7 (A14); also elsewhere on the board
/SoC/SA15: U2.M7 (A15); also elsewhere on the board
/SoC/SBA0: U2.M2 (BA0); also elsewhere on the board
/SoC/SBA1: U2.N8 (BA1); also elsewhere on the board
/SoC/SBA2: U2.M3 (BA2); also elsewhere on the board
/SoC/SCAS: U2.K3 (~CAS); also elsewhere on the board
/SoC/SCK+: R5.1, U2.J7 (CK); also elsewhere on the board
/SoC/SCK-: R5.2, U2.K7 (~CK); also elsewhere on the board
/SoC/SCKE0: U2.K9 (CKE); also elsewhere on the board
/SoC/SCS0: U2.L2 (~CS); also elsewhere on the board
/SoC/SDQ0: U2.F8 (DQ3); also elsewhere on the board
/SoC/SDQ1: U2.H8 (DQ5); also elsewhere on the board
/SoC/SDQ2: U2.F7 (DQ1); also elsewhere on the board
/SoC/SDQ3: U2.G2 (DQ6); also elsewhere on the board
/SoC/SDQ4: U2.H7 (DQ7); also elsewhere on the board
/SoC/SDQ5: U2.E3 (DQ0); also elsewhere on the board
/SoC/SDQ6: U2.F2 (DQ2); also elsewhere on the board
/SoC/SDQ7: U2.H3 (DQ4); also elsewhere on the board
/SoC/SDQ8: U2.A7 (DQ12); also elsewhere on the board
/SoC/SDQ9: U2.B8 (DQ14); also elsewhere on the board
/SoC/SDQ10: U2.C8 (DQ10); also elsewhere on the board
/SoC/SDQ11: U2.D7 (DQ8); also elsewhere on the board
/SoC/SDQ12: U2.A3 (DQ15); also elsewhere on the board
/SoC/SDQ13: U2.A2 (DQ13); also elsewhere on the board
/SoC/SDQ14: U2.C3 (DQ9); also elsewhere on the board
/SoC/SDQ15: U2.C2 (DQ11); also elsewhere on the board
/SoC/SDQM0: U2.E7 (LDM); also elsewhere on the board
/SoC/SDQM1: U2.D3 (UDM); also elsewhere on the board
/SoC/SDQS0+: U2.F3 (LDQS); also elsewhere on the board
/SoC/SDQS0-: U2.G3 (~LDQS); also elsewhere on the board
/SoC/SDQS1+: U2.C7 (UDQS); also elsewhere on the board
/SoC/SDQS1-: U2.B7 (~UDQS); also elsewhere on the board
/SoC/SODT0: U2.K1 (ODT); also elsewhere on the board
/SoC/SRAS: U2.J3 (~RAS); also elsewhere on the board
/SoC/SRST: U2.T2 (~RESET); also elsewhere on the board
/SoC/SWE: U2.L3 (~WE); also elsewhere on the board
GND: C2.2, C3.2, C4.2, C5.2, C6.2, C7.2, C8.2, C9.2, C10.2, C44.2, R2.2, R4.2, U2.A9 (VSS), U2.B1 (VSSQ), U2.B3 (VSS), U2.B9 (VSSQ), U2.D1 (VSSQ), U2.D8 (VSSQ), U2.E1 (VSS), U2.E2 (VSSQ), U2.E8 (VSSQ), U2.F9 (VSSQ), U2.G1 (VSSQ), U2.G8 (VSS), U2.G9 (VSSQ), U2.J2 (VSS), U2.J8 (VSS), U2.M1 (VSS), U2.M9 (VSS), U2.P1 (VSS), U2.P9 (VSS), U2.T1 (VSS), U2.T9 (VSS), U8.4 (GND), U8.9 (EP); also elsewhere on the board
unnamed: R2.1, U2.L8 (ZQ)
SPI0_CLK: U8.6 (CLK); also elsewhere on the board
SPI0_CS: U8.1 (~CS); also elsewhere on the board
SPI0_MISO: U8.2 (DO/IO_{1}); also elsewhere on the board
SPI0_MOSI: U8.5 (DI/IO_{0}); also elsewhere on the board
VREF: C1.2, C2.1, R3.2, R4.1, U2.H1 (VREFDQ), U2.M8 (VREFCA); also elsewhere on the board

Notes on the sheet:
Termination under dram chip
NOR FLASH (OPTIONAL)

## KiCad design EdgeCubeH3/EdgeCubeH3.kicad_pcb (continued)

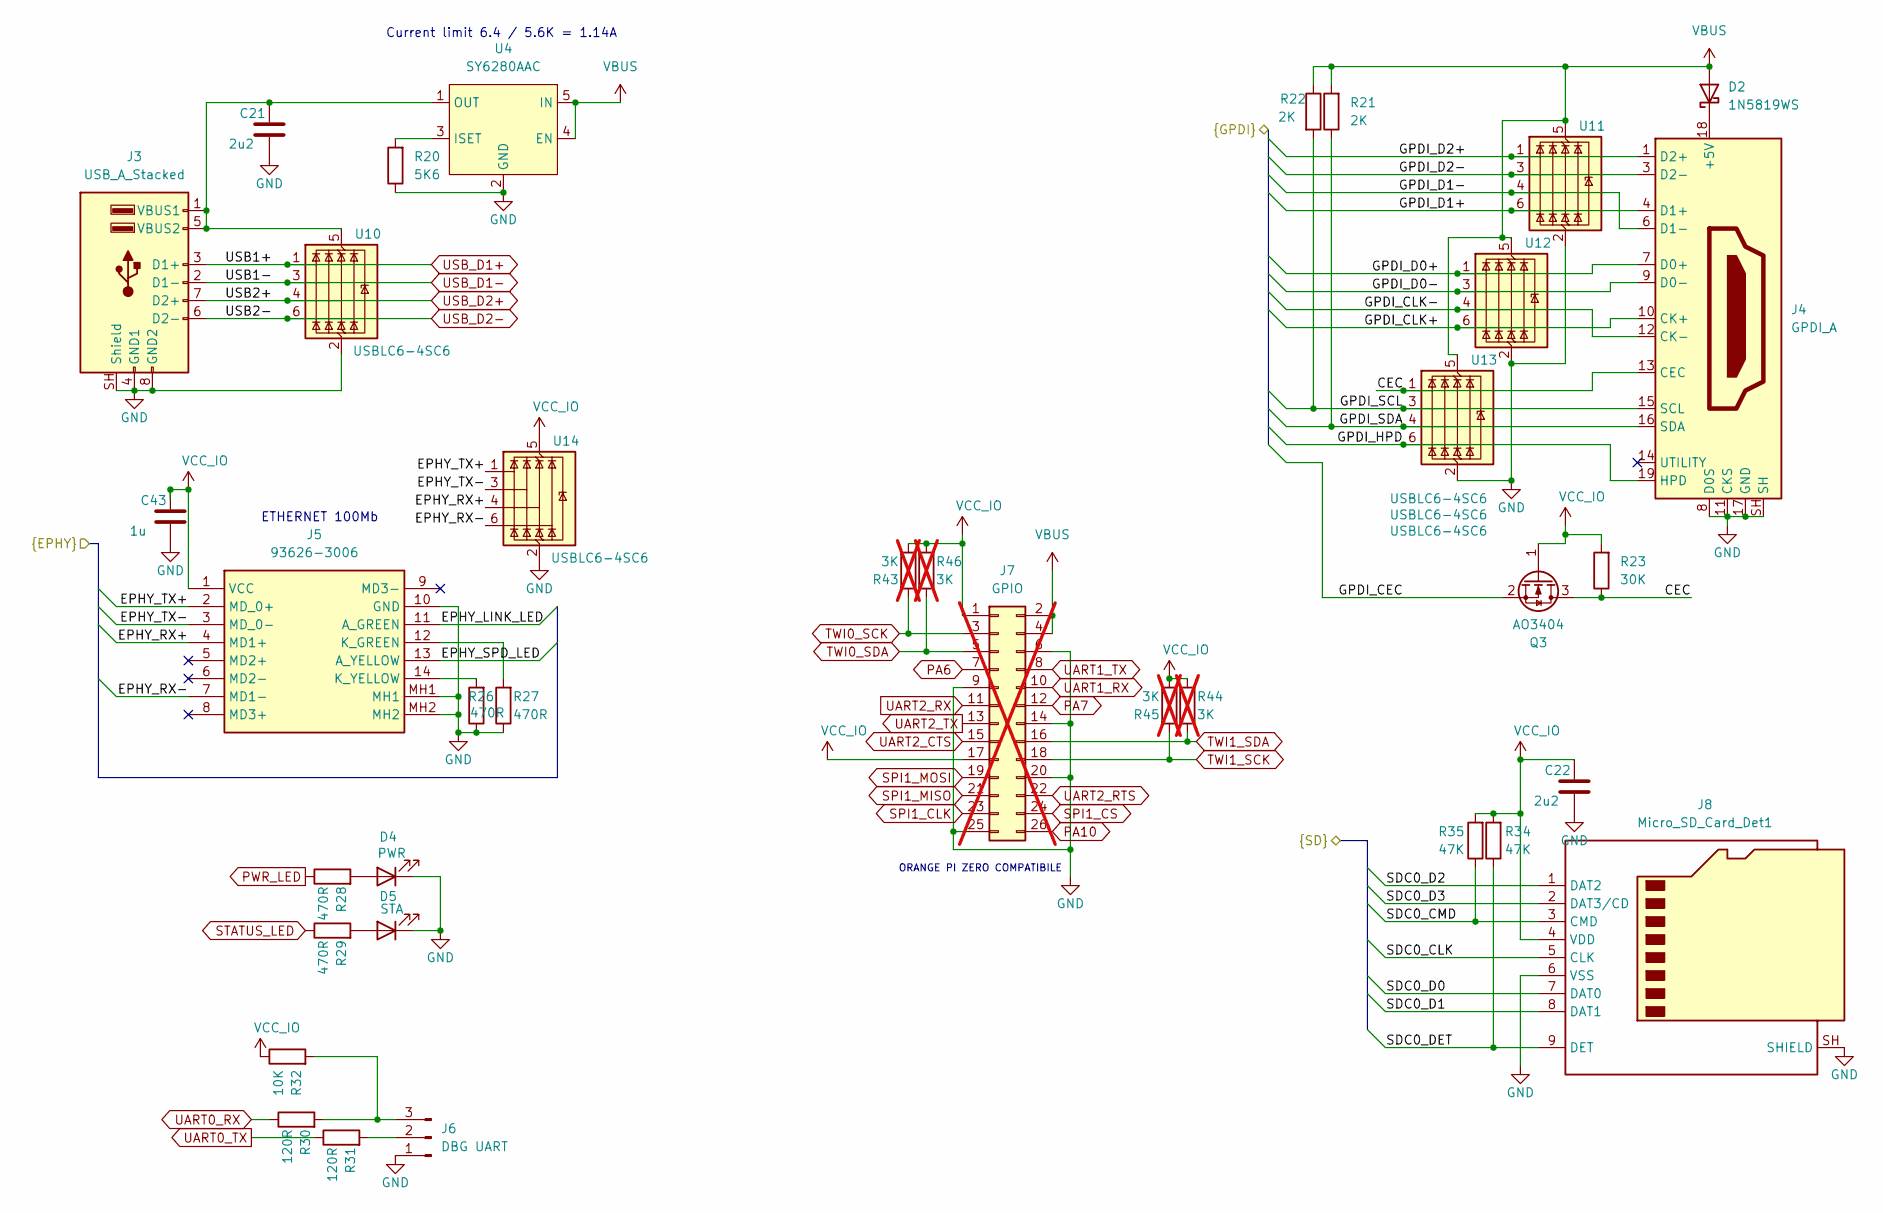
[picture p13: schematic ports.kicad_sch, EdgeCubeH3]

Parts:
C21, C22: 2u2; C_0603_1608Metric
C43: 1u; C_0603_1608Metric
D2: 1N5819WS; D_SOD-323
D4: PWR; LED_0805_2012Metric
D5: STA; LED_0805_2012Metric
J3: USB_A_Stacked; USB_A_CUI_UJ2-ADH-TH_Horizontal_Stacked
J4: GPDI_A; HDMI_A_Molex_208658-1001_Horizontal
J5: 93626-3006; 936263006; Mouser Part Number 538-93626-3006
J6: DBG UART; PinHeader_1x03_P2.54mm_Vertical
J7: GPIO; PinHeader_2x13_P2.54mm_Vertical; not fitted
J8: Micro_SD_Card_Det1; microSD_TF-01A
Q3: AO3404; SOT-23
R20: 5K6; R_0603_1608Metric
R21, R22: 2K; R_0603_1608Metric
R23: 30K; R_0603_1608Metric
R26, R27, R28, R29: 470R; R_0603_1608Metric
R30, R31: 120R; R_0603_1608Metric
R32: 10K; R_0603_1608Metric
R34, R35: 47K; R_0603_1608Metric
R43, R44, R45, R46: 3K; R_0603_1608Metric; not fitted
U4: SY6280AAC; SOT-23-5; LCSC Part # C55136
U10, U11, U12, U13, U14: USBLC6-4SC6; SOT-23-6

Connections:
/SoC/EPHY_LINK_LED: J5.11 (A_GREEN); also elsewhere on the board
/SoC/EPHY_RX+: J5.4 (MD1+), U14.4 (I/O3); also elsewhere on the board
/SoC/EPHY_RX-: J5.7 (MD1-), U14.6 (I/O4); also elsewhere on the board
/SoC/EPHY_SPD_LED: J5.13 (A_YELLOW); also elsewhere on the board
/SoC/EPHY_TX+: J5.2 (MD_0+), U14.1 (I/O1); also elsewhere on the board
/SoC/EPHY_TX-: J5.3 (MD_0-), U14.3 (I/O2); also elsewhere on the board
/SoC/GPDI_CEC: Q3.2 (S); also elsewhere on the board
/SoC/GPDI_CLK+: J4.10 (CK+), U12.6 (I/O4); also elsewhere on the board
/SoC/GPDI_CLK-: J4.12 (CK-), U12.4 (I/O3); also elsewhere on the board
/SoC/GPDI_D0+: J4.7 (D0+), U12.1 (I/O1); also elsewhere on the board
/SoC/GPDI_D0-: J4.9 (D0-), U12.3 (I/O2); also elsewhere on the board
/SoC/GPDI_D1+: J4.4 (D1+), U11.6 (I/O4); also elsewhere on the board
/SoC/GPDI_D1-: J4.6 (D1-), U11.4 (I/O3); also elsewhere on the board
/SoC/GPDI_D2+: J4.1 (D2+), U11.1 (I/O1); also elsewhere on the board
/SoC/GPDI_D2-: J4.3 (D2-), U11.3 (I/O2); also elsewhere on the board
/SoC/GPDI_HPD: J4.19 (HPD), U13.6 (I/O4); also elsewhere on the board
/SoC/GPDI_SCL: J4.15 (SCL), R22.2, U13.3 (I/O2); also elsewhere on the board
/SoC/GPDI_SDA: J4.16 (SDA), R21.1, U13.4 (I/O3); also elsewhere on the board
/SoC/SDC0_CLK: J8.5 (CLK); also elsewhere on the board
/SoC/SDC0_CMD: J8.3 (CMD), R35.1; also elsewhere on the board
/SoC/SDC0_D0: J8.7 (DAT0); also elsewhere on the board
/SoC/SDC0_D1: J8.8 (DAT1); also elsewhere on the board
/SoC/SDC0_D2: J8.1 (DAT2); also elsewhere on the board
/SoC/SDC0_D3: J8.2 (DAT3/CD); also elsewhere on the board
/SoC/SDC0_DET: J8.9 (DET), R34.1; also elsewhere on the board
/ports/CEC: J4.13 (CEC), Q3.3 (D), R23.1, U13.1 (I/O1)
GND: C21.2, C22.2, C43.2, D4.1 (K), D5.1 (K), J3.4 (GND1), J3.8 (GND2), J3.SH (Shield), J4.2 (D2S), J4.5 (D1S), J4.8 (D0S), J4.11 (CKS), J4.17 (GND), J4.SH, J5.10 (GND), J5.MH1, J5.MH2, J6.1, J7.6, J7.9, J7.14, J7.20, J7.25, J8.6 (VSS), J8.SH (SHIELD), R20.1, R26.1, R27.1, U4.2 (GND), U10.2 (GND), U11.2 (GND), U12.2 (GND), U13.2 (GND), U14.2 (GND); also elsewhere on the board
unnamed: D2.1 (K), J4.18 (+5V)
unnamed: D4.2 (A), R28.2
unnamed: D5.2 (A), R29.2
unnamed: C21.1, J3.1 (VBUS1), J3.5 (VBUS2), U4.1 (OUT), U10.5 (VBUS)
unnamed: J5.12 (K_GREEN), R27.2
unnamed: J5.14 (K_YELLOW), R26.2
unnamed: J6.2, R31.2
unnamed: J6.3, R30.2, R32.2
unnamed: R20.2, U4.3 (ISET)
PA6: J7.7; also elsewhere on the board
PA7: J7.12; also elsewhere on the board
PA10: J7.26; also elsewhere on the board
PWR_LED: R28.1; also elsewhere on the board
SPI1_CLK: J7.23; also elsewhere on the board
SPI1_CS: J7.24; also elsewhere on the board
SPI1_MISO: J7.21; also elsewhere on the board
SPI1_MOSI: J7.19; also elsewhere on the board
STATUS_LED: R29.1; also elsewhere on the board
TWI0_SCK: J7.3, R43.2; also elsewhere on the board
TWI0_SDA: J7.5, R46.1; also elsewhere on the board
TWI1_SCK: J7.18, R45.2; also elsewhere on the board
TWI1_SDA: J7.16, R44.1; also elsewhere on the board
UART0_RX: R30.1; also elsewhere on the board
UART0_TX: R31.1; also elsewhere on the board
UART1_RX: J7.10; also elsewhere on the board
UART1_TX: J7.8; also elsewhere on the board
UART2_CTS: J7.15; also elsewhere on the board
UART2_RTS: J7.22; also elsewhere on the board
UART2_RX: J7.11; also elsewhere on the board
UART2_TX: J7.13; also elsewhere on the board
USB_D1+: J3.3 (D1+), U10.1 (I/O1); also elsewhere on the board
USB_D1-: J3.2 (D1-), U10.3 (I/O2); also elsewhere on the board
USB_D2+: J3.7 (D2+), U10.4 (I/O3); also elsewhere on the board
USB_D2-: J3.6 (D2-), U10.6 (I/O4); also elsewhere on the board
VBUS: D2.2 (A), J7.2, J7.4, R21.2, R22.1, U4.4 (EN), U4.5 (IN), U11.5 (VBUS), U12.5 (VBUS), U13.5 (VBUS); also elsewhere on the board
VCC_IO: C22.1, C43.1, J5.1 (VCC), J7.1, J7.17, J8.4 (VDD), Q3.1 (G), R23.2, R32.1, R34.2, R35.2, R43.1, R44.2, R45.1, R46.2, U14.5 (VBUS); also elsewhere on the board

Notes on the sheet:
ETHERNET 100Mb
Current limit 6.4 / 5.6K = 1.14A
ORANGE PI ZERO COMPATIBILE

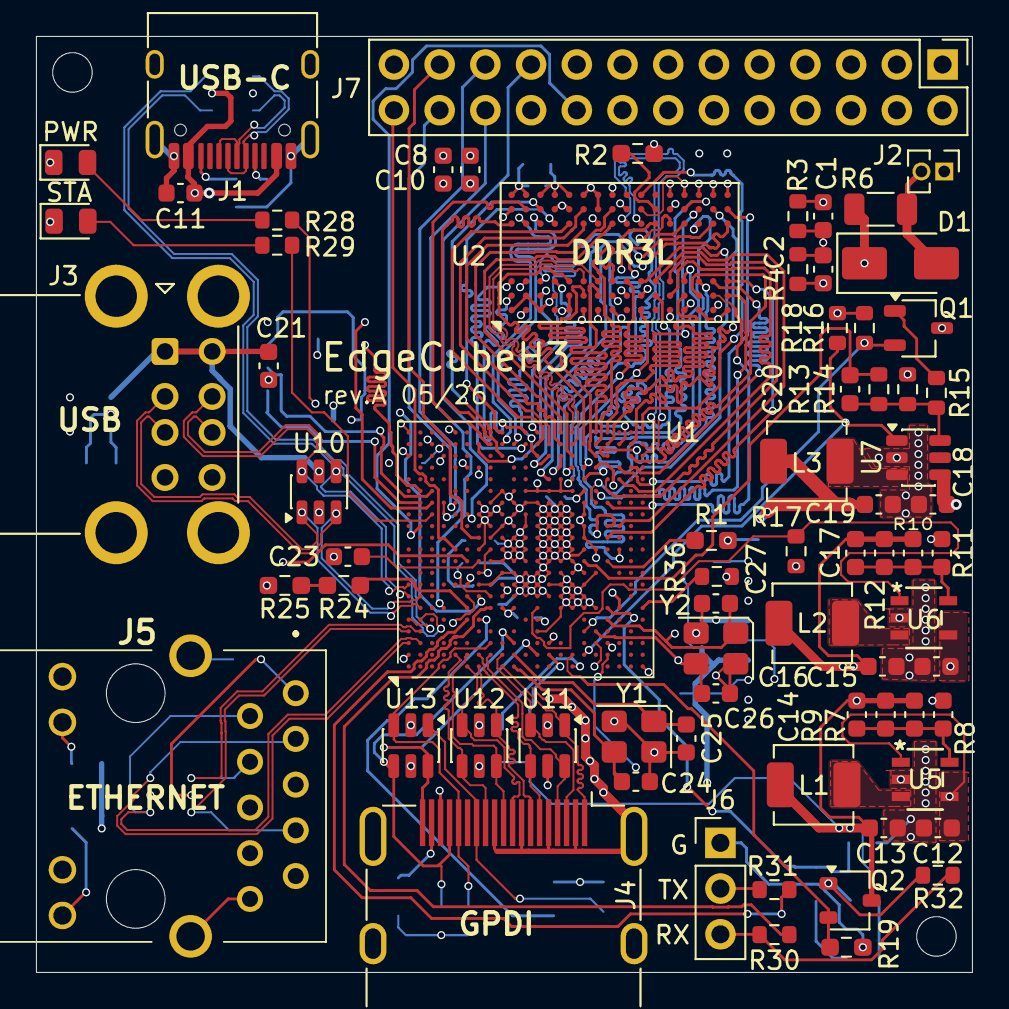
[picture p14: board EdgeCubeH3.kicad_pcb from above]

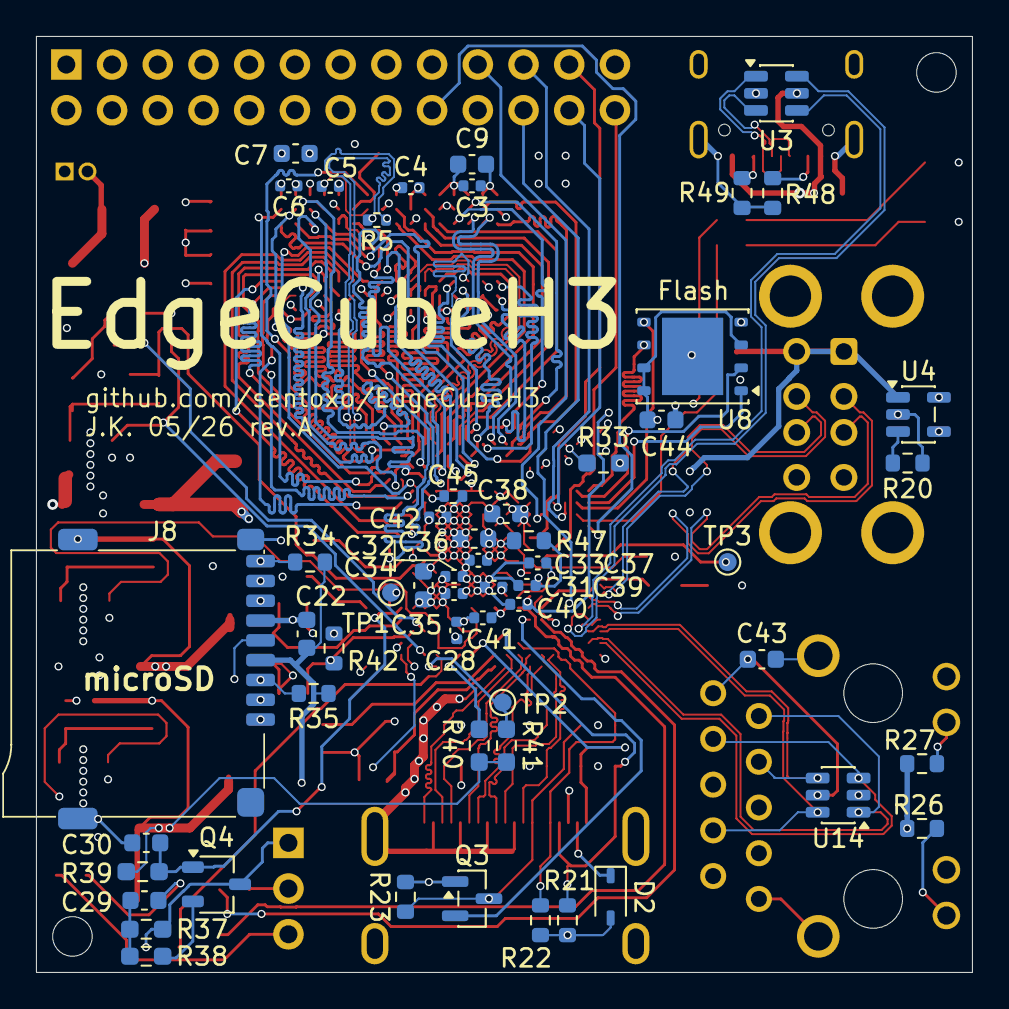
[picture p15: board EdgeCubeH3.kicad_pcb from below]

Board: 6 copper layers, 52.0 x 52.0 mm, 129 parts (55 on the bottom side), 159 nets.

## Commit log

2026-05-10 Schematic update, PCB started
    [EdgeCubeH3.kicad_pcb, SoC.kicad_sch, dram.kicad_sch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]
2026-05-17 PCB design at ~90%
    - re-arrangement of components
    - connecting dram
    - connecting ports
    [EdgeCubeH3.kicad_pcb, SoC.kicad_sch, dram.kicad_sch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]
2026-05-18 PCB at 95%
    [EdgeCubeH3.kicad_pcb, SoC.kicad_sch]
2026-05-19 PCB at 98%
    [EdgeCubeH3.kicad_pcb, ports.kicad_sch]
2026-05-20 Compleating PCB design
    [EdgeCubeH3.kicad_pcb, SoC.kicad_sch, dram.kicad_sch]
2026-05-21 Small changes to PCB, updated schematic and readme
    [EdgeCubeH3.kicad_pcb, EdgeCubeH3.kicad_sch, SoC.kicad_sch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]
2026-05-23 Finalization of rev.A
    [EdgeCubeH3.kicad_pcb, power.kicad_sch]
